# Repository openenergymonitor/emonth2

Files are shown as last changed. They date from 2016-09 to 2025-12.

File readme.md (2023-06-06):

# emonTH V2.0

**Low power wireless temperature and humidity node**

*V2.0 hardware revision adds support for SI7021 temperature and humidity. This sensor brings performance and power savings over the DHT22, see [sensor](sensor) folder of this repo for sensor evaluation and comparison.*

The emonTH V2 is an open-source, wireless, battery powered temperature and humidity monitoring node.

Data from the emonTH is transmitted via wireless RF (433MHz) to an emonPi / emonBase web-connected base-station for logging to Emoncms for data logging, processing and graphing.

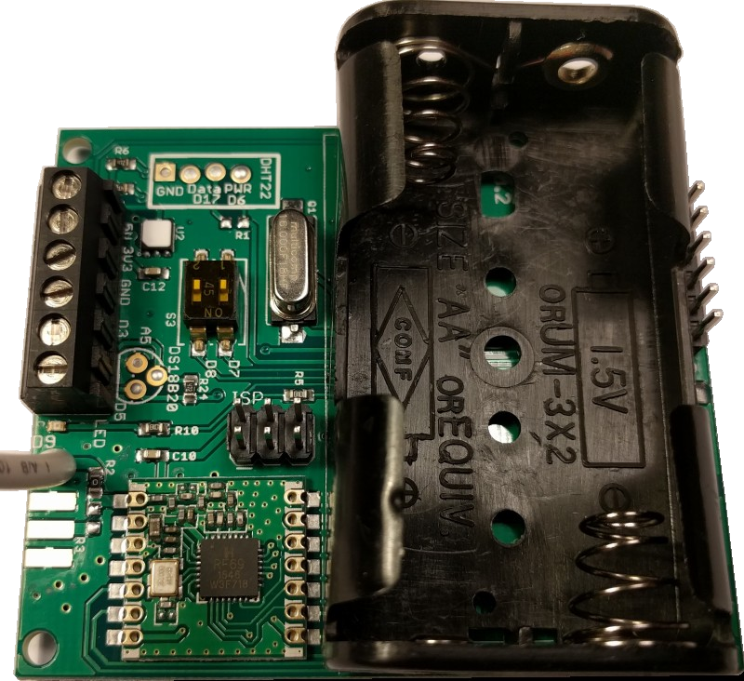
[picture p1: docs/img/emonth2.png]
emonTH V2


## Documentation

- [Overview](https://docs.openenergymonitor.org/emonth2/overview.html)
- [Installation](https://docs.openenergymonitor.org/emonth2/install.html)
- [Firmware](https://docs.openenergymonitor.org/emonth2/firmware.html)
- [Configuration](https://docs.openenergymonitor.org/emonth2/configuration.html)
- [Technical](https://docs.openenergymonitor.org/emonth2/technical.html)

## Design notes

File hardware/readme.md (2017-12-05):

# Board

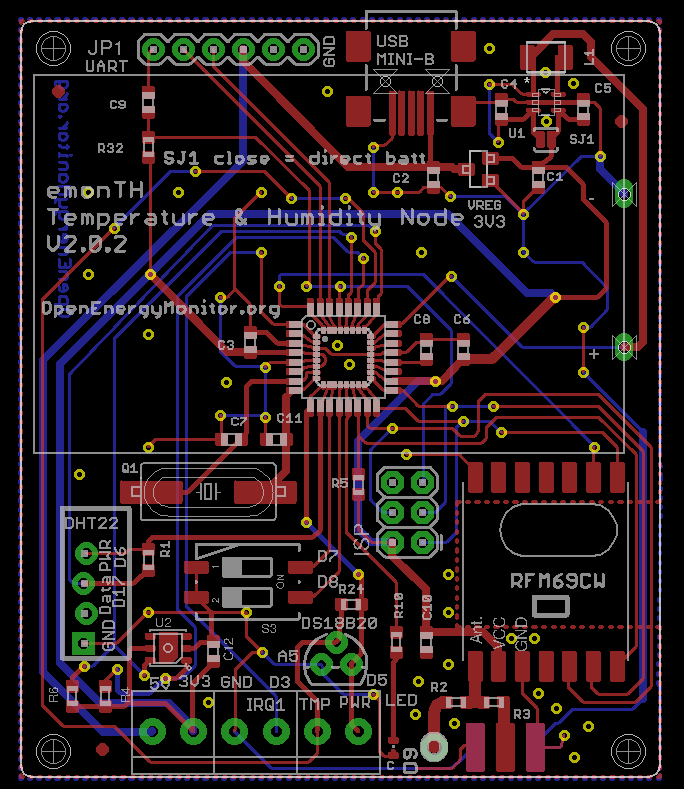
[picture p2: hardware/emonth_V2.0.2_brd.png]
board


# Schematic

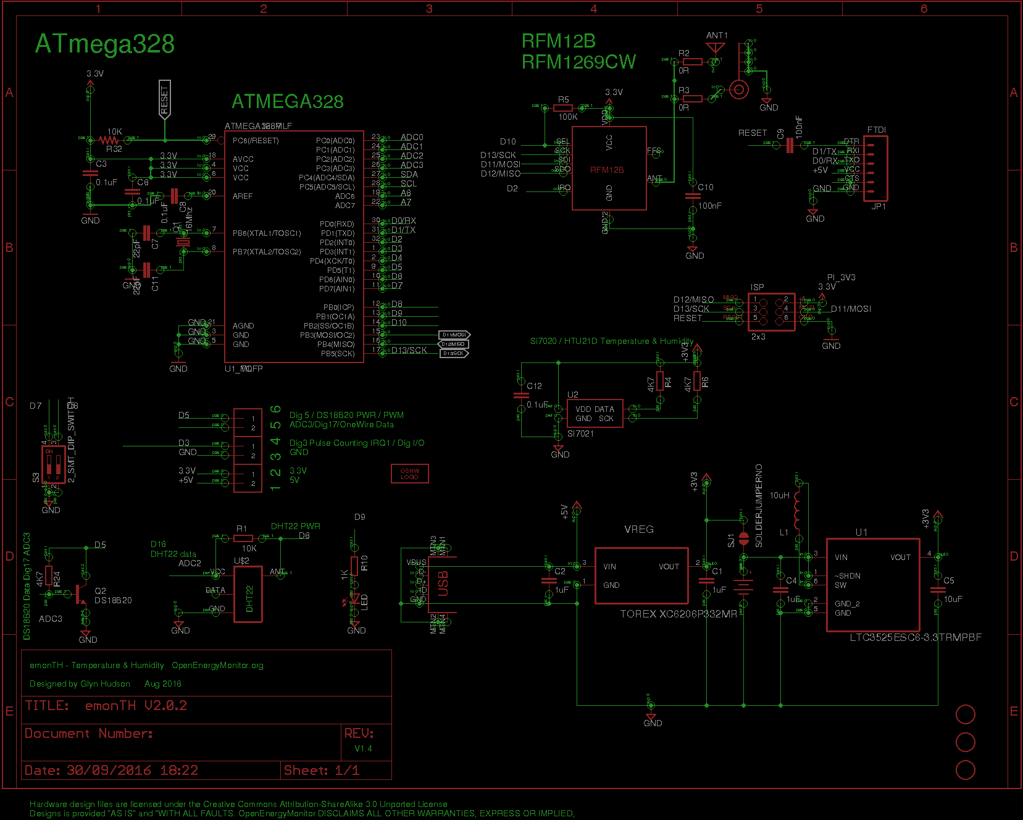
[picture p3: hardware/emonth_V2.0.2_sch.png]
emonTH V2 schematic


# Change log

## V2.0.2 (26th Sep 2016)

- Fix LED trace

## V2.0.1 (Aug 2016)

- Add SI7021 temperature & humidity sensor (see `si7021_eval` folder in emonth2 repo)
- Re-jig port map from emonTH V1.5 to make available I2C pins for SI7021

# Port Map

| | | | |
|---|---|---|---|
| Arduino | ATmega328 | Function | emonTH V2 |
| Analog 0 (D14) | PC0 | | |
| Analog 1 (D15) | PC1 | | 2x AA Battery Voltage |
| Analog 2 (D16) | PC2 | | DHT22 Data |
| Analog 3 (D17) | PC3 | | DS18B20 One-wire Data |
| Analog 4 (D18) | PC4 | (SDA) | SI7021 SDA (Data) |
| Analog 5 (D19) | PC5 | (SCL) | SI7021 SCL (SCK) |
| Analog 6 (D20) | | | |
| Analog 7 (D21) | | | |
| Digital 0 | PD0 | (RXD) | FTDI Tx |
| Digital 1 | PD1 | (TXD) | FTDI Rx |
| Digital 2 | PD2 | (int0) PWM | RFM69CW IRQ |
| Digital 3 | PD3 | (int1) PWM | Terminal block |
| Digital 4 | PD4 | | |
| Digital 5 | PD5 | PWM | DS18B20 PWR |
| Digital 6 | PD6 | PWM | DHT22 PWR |
| Digital 7 | PD7 | | DIP 1 |
| Digital 8 | PB0 | | DIP 2 |
| Digital 9 | PB1 | PWM | LED |
| Digital 10 | PB2 | (SS) PWM | RFM69CW SEL |
| Digital 11 | PB3 | (MOSI) PWM | RFM69CW SDI |
| Digital 12 | PB4 | (MISO) | RFM69CW SDO |
| Digital 13 | PB5 | (SCK) | RFM69CW SCK |

# BOM

|Qty |Value |Device |Package |Parts |Description |
|----|---|---|---|---|---|
|1 | |ANTENNA |PAD-01 |ANT1 |Antenna |
|1 | |LEDCHIPLED-0603-TTW  |CHIPLED-0603-TTW|LED |LED |
|4 |0.1uF |C-EUC0603 |C0603 |C3, C6, C8, C12|CAPACITOR, European symbol |
|2 |0R |R-EU_R0603 |R0603 |R2, R3 |RESISTOR, European symbol |
|1 |100K |R-EU_R0603 |R0603 |R5 |RESISTOR, European symbol |
|2 |100nF |C-EUC0603 |C0603 |C9, C10 |CAPACITOR, European symbol |
|1 |10K |R-EU_R0603 |R0603 |R1 |RESISTOR, European symbol |
|1 |10K |R-US_R0603 |R0603 |R32 |RESISTOR, American symbol |
|1 |10uF |C-EUC0603 |C0603 |C5 |CAPACITOR, European symbol |
|1 |10uH |INDUCTOR1210 |1210 |L1 |Inductors |
|1 |16Mhz |CRYSTALHC49UP |HC49UP |Q1 |CRYSTAL |
|1 |1K |R-EU_R0603 |R0603 |R10 |RESISTOR, European symbol |
|3 |1X2-3.5MM |1X2-3.5MM |1X2-3.5MM |J1, J2, J3 |3.5mm Terminal block |
|3 |1uF |C-EUC0603 |C0603 |C1, C2, C4 |CAPACITOR, European symbol |
|2 |22pF |C-EUC0603 |C0603 |C7, C11 |CAPACITOR, European symbol |
|1 |2_SMT_DIP_SWITCH |2_SMT_DIP_SWITCH |DIP_SWITCH_SMT  |S3 |Multicomp MCEMR-02-T |
|1 |2x3 |AVR_SPI_PRG_6PTH |2X3 |ISP |AVR ISP 6 Pin |
|1 |3V |3X_AAA_BATTERY_HOLDER|AAA_PCB_HOLDER  |U$3 |2x AA Battery Holder |
|3 |4K7 |R-EU_R0603 |R0603 |R4, R6, R24 |RESISTOR, European symbol |
|1 |ATMEGA168MLF |ATMEGA168MLF |MLF32 |U1_MLF |Atmel 32-pin 8-bit micro, 16k flash. |
|1 |ATMEGA328P |ATMEGA328_SMT |TQFP32-08 |U1_TQFP |32-Pin Atmega328 part |
|1 |DS18B20 |TRANSISTOR_NPNTO92 |TO-92 |Q2 |Transistor NPN |
|3 |FIDUCIAL |FIDUCIAL |FIDUCIAL_1MM |U$1, U$6, U$7  |For use by pick and place machines to calibrate the vision/machine, 1mm|
|1 |FTDI |FTDI_BASICPTH |FTDI_BASIC |JP1 |FTDI Basic: 3.3V and 5V |
|1 |LTC3525ESC6-3.3TRMPBF|LTC3525ESC6-3.3TRMPBF|SOT65P210X100-6N|U1 |Step-Up DC/DC Converter |
|1 |RF-LINK_TX |RF-LINK_TX |RF-LINK_TX |U$2 | |
|1 |RFM12B |RFM12B |RFM12B |RFM69CW | |
|1 |SI7021 |SI7021 |SI7021 |U2 |The Si7021 is an I2C Humidity and Temperature Sensor |
|1 |SMA_EDGE |SMA_EDGE |SMA-EDGE |J$1 |SMA Antenna Connector |
|1 |SOLDERJUMPERNO |SOLDERJUMPERNO |SJ_2S-NO |SJ1 |Solder Jumper |
|1 |TOREX XC6206P332MR |MCP1700T-3302E/TT |SOT95P237X112-3N|VREG |Low Quiescent Current LDO |
|1 |USB-MINIB-5PIN |USB-MINIB-5PIN |USB-MINIB-CISECO|U$5 |Mini-USB "B" connector with 5th pin broken out. |

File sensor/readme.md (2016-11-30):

# Temperature & Humidity Sensor Evaluation and Testing

| Metric | [HTU21D](https://octopart.com/htu21d-measurement+specialties-30374934) |[Si72021](https://octopart.com/si7021-a20-im-silicon+labs-52675246)| DHT22 | DHT22 vs HTU21D Difference| [BME280](https://octopart.com/bme280-bosch-52931981) |
| --- | ---|--- | --- | --- | --- |
| Cost in 1k off | £2.15|  £4.57 (July16) | 3.2 times cheaper (£3.15 less!) | £3.07 |
| Vcc |  1.9V - 3.6V | 3.3-6V | | 1.71 V - 3.6V |
| Humidity accuracy |  ±2% RH |  ±2%RH | n/a | ±3%RH |
| Humidity Range |  0-100% RH |  0-100% RH | n/a|  0-100% RH  |
| Temperature accuracy | ±0.4°C|  ±0.5°C | 40% more accurate | ±0.5 - ±1.0 |
| Temperature Range | -40°C +125°C  |  -40°C +80°C | 56% more accurate | -40°C +80°C  |
| Sleep Current | 0| 0.06uA |  15uA | 750 times less power | 0.1uA - 0.3uA |
| Measurement Current | 0. 0.09 mA |  0.5mA | 11 times less power | 0.714mA - 0.350mA |
| Measurement time | 0.01s | 0.01s - 0.0026s |  2s | 200 times faster | 0.013s |
| Energy consumed per sample| 2.97uJ |  3300uJ | 2000 times less power | |
| Time sampling per day* ||  2800s | | |
| Time sleeping per day* | |  83600s | | |
| Energy consumed per day*  ||  8700mJ [2] | 1115 times less energy per day!  | |

```
energy consumed (joule, J) = potential difference (volt, V) × charge (coulomb, C)
charge (coulomb, C) = current (ampere, A) × time (second, s)
energy consumed (joule, J)  = potential difference (volt, V) × current (ampere, A) × time (second, s)
```

## Energy consumed per day*

Energy consumed per day = energy consumed per sample + energy consumed while sleeping.

- **HTU21D:** (1400 * 0.0015mJ) + (3.3V * 0.00002mA * 86386 ) = 2.1mJ + 5.7mJ = 7.8mJ [1]
- **DHT22:**  (1400 * 3.3mJ) + (3.3V * 0.015mA * 83600) = 4.6mJ + 4.1J = 8.7J = 8700mJ   [2]

\*Assuming 1 sample per min and sleeping in between samples: 1400 samples per day

[Adafruit HTU21D Library](https://github.com/adafruit/Adafruit_HTU21DF_Library)

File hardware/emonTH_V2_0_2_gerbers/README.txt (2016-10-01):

# emonTx TH V2.0.2 - Sep 2016

- PCB to be 1.6mm thickness
- Solder Resist: Blue
- Finish: HASL

* No silkscreen should overlap pads
* Check Welsh Daragon logo on the rear is re-produced OK :-)

glyn.hudson@openenergymonitor.org
Tel: +441248672607
Mob: +447769871550

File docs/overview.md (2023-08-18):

<a class="btn" href="https://shop.openenergymonitor.com/emonth-temperature-humidity-node/">Buy in Shop</a>

# Overview

The emonTH V2 is an open-source, wireless, battery-powered temperature and humidity monitoring node.

Data from the emonTH is transmitted via wireless RF (433MHz) to an emonPi / emonBase web-connected base-station for logging to Emoncms for data logging, processing and graphing.

The emonTH V2 features a [Silicon Labs Si7021](https://www.silabs.com/Support%20Documents%2FTechnicalDocs%2FSi7021-A20.pdf) temperature and humidity sensor instead of the DHT22 sensor. The Si7021 is more accurate and significantly (2000 times!) lower power then the DHT22. This increases the emonTH battery life; from 10 months to several years. The Si7021 is also much smaller than the DHT22.

emonTH V2

The Si7021 sensor can be seen in the top right-hand corner of the PCB. The white film on top of the sensor is a dust film and should not be removed. The dust film is factory fitted and will protect the sensor from dust and air contaminants.

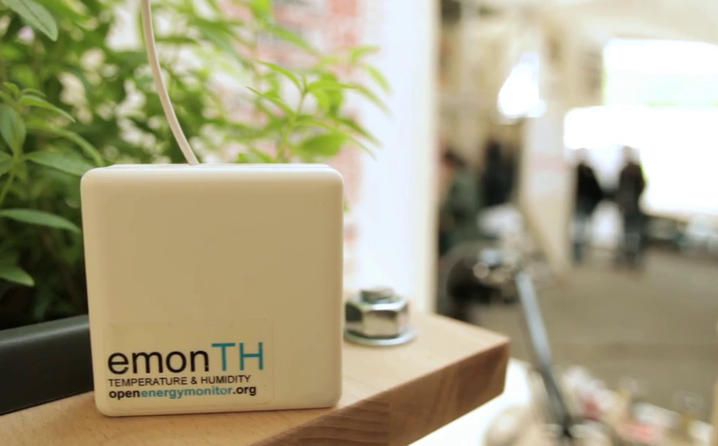
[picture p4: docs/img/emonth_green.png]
emonTH V2


As with all our hardware units the emonTH V2 is fully open-source and manufactured locally in North Wales, UK using non-conflict materials lead-free processes.

**emonTH V2 Features**

- Wireless temperature & humidity monitoring node
- Communicates with emonPi & emonBase via RF (433Mhz)
- 1yr+ battery life (2 x AA not included)
- Up to 4x emonTH can communicate to a single emonPi*
- Internal temperature & humidity + optional external probe
- Optional pulse sensor input

\* *More than 4x emonTH units can be connected to a single emonPi / emonBase with manual change of RF nodeID. This can be done via [serial node ID config](https://community.openenergymonitor.org/t/emontx-emonth-configure-rf-settings-via-serial-released-fw-v2-6-v3-2/2064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)*

- Microcontroller: Arduino compatible ATmega328p
- Internal Sensor: Si7021 (internal temperature & Humidity)
- External Sensor (OPTIONAL): DS18B20 external temperature sensor. See hardware wiki for connections
- Power: 2 x AA from onboard holder, LTC3525 3.3V DC-DC boost converter to extend battery life
- RF Radio: RFM69CW 433Mhz

**Si7021 Temperature & Humidity Sensor**

- Silicon Labs SI7021-A20-GM1R
- Power supply 1.9V - 3.6V
- Operating range humidity 0-80%RH; temperature -40~125 deg C
- Accuracy humidity +-3%RH
- Accuracy Temperature: +-0.4 degC
- Active current: 150uA
- Sleep current 0.06uA
- Measurement time: 2.6ms = 10ms

[See DHT22 VS Si7021 technical comparison table](https://github.com/openenergymonitor/emonth2/tree/master/sensor)

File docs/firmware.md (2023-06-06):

# Firmware

The emonTH2 firmware is based on Arduino.

## Available Firmware

### [emonTh2](https://github.com/openenergymonitor/emonth2/tree/master/firmware):

**New:** Support for three different radio formats is available: JeeLib Classic, JeeLib Native and **LowPowerLabs**.

## Updating firmware using an emonPi/emonBase

The easiest way of updating the emonTh2 firmware is to connect it to an emonPi or emonBase with a USB to UART cable and then use the firmware upload tool available at `Setup > Admin > Update > Firmware`.

The example images below show the earlier [Wicked Device / OpenEnergyMonitor Programmer](../electricity-monitoring/programmers/wicked-device.md). The programmer is the small board that plugs in to the emonTh2 on the 6-pin UART header. The [newer programmer](../electricity-monitoring/programmers/ftdi-programmer.md) currently available in the shop needs to be orientated the other way around. **Make sure that GND on the programmer matches up with GND on the emonTh2 board.**

Refresh the update page after connecting the USB cable. You should now see port ttyUSB0 appear in the ‘Select port` list.

*emonPi to emonTh2 programmer image*

Select port: `ttyUSB0`, Hardware: `emonTh2`, Radio format e.g: `RFM69 LowPowerLabs`:

*emonTh firmware upload image*

Click `Update Firmware` to upload the firmware.

## Upload using avrdude

Pre compiled firmware can be uploaded using a USB to UART programmer and avrdude: 

`avrdude -uV -c arduino -p ATMEGA328P -P /dev/ttyUSB0  -b 115200 -U flash:w:firmware.hex`

## How to compile and upload firmware

### PlatformIO Command Line

PlatformIO works great from the command line. See the excellent [PlatformIO Quick Start Guide](https://docs.platformio.org/en/latest/core/installation/index.html#super-quick-mac-linux) for installation instructions.

**Compile and upload emonTh2 firmware**

    git clone https://github.com/openenergymonitor/emonth2
    cd emonth2/firmware
    pio run -t upload

**View serial port with PlatformIO CLI**

    pio device monitor

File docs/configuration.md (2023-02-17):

# Configuration

- Battery operation is expected, although 5 V d.c. can be supplied via the FTDI connector or the screw terminal block if desired.
- Transmits readings from internal temperature and humidity sensor, also external DS18B20 temperature sensor can be connected if desired.
- Settings can be adjusted at power-up using the FTDI connector and a serial programmer.

## Setting up

Data is transmitted by radio approximately every 58 s, identified as Node 23. Changing the internal DIP switches before power-up can change this to Node 24, 25 or 26.

Adding an external temperature sensor before power-up will allow it to be recognised and the readings automatically included in the sent data.

## Additional set-up options

At power-up, if you have a serial monitor connected via the FTDI connector and set to 115200 baud with “both NL & CR” selected, you will see a “Welcome” message giving the software version number, the radio, pulse counter and temperature settings, and some more diagnostic messages. At the end is an invitation to enter the access code **+++**. You have a 5 s window to enter that (or you may ignore it, when after the delay, the emonTH will start up, you will see nothing more and you will not be able to change anything until you restart the sketch).

If you successfully enter the access code, you will see an advisory and a short menu:

Entering Settings mode...

Available commands:

- **l** list the settings
- **r** restore sketch defaults
- **s** save settings to EEPROM
- **v** show firmware version
- **x** exit, lock and continue
- **?** show this text again

- **w\<x\>** turn RFM Wireless data off: x = 0 or on: x = 1
- **b\<n\>** set r.f. band n = a single numeral: 4 = 433MHz, 8 = 868MHz, 9 = 915MHz (may require hardware change)
- **p\<nn\>** set the r.f. power. nn - an integer 0 - 31 representing -18 dBm to +13 dBm. Default: 25 (+7 dBm)
- **g\<nnn\>** set Network Group nnn - an integer (OEM default = 210)
- **n\<nn\>** set node ID n= an integer (standard node ids are 1..60)

- **m\<x\> \<yy\>** meter pulse counting:
  - x = 0 for OFF, x = 1 for ON, 
  - \<yy\> = an integer for the pulse minimum period in ms. (y is not needed, or ignored when x = 0)

- **t0 \<y\>** turn external temperature measurement on or off: y = 0 for OFF, y = 1 for ON

- **t\<x\> \<yy\> \<yy\> \<yy\> \<yy\> \<yy\> \<yy\> \<yy\> \<yy\>**
  - change an external temperature sensor's address or position:
  - x = a single numeral: the position of the sensor in the list (1-based)
  - yy = 8 hexadecimal bytes representing the sensor's address
  - e.g. 28 81 43 31 07 00 00 D
  - N.B. Sensors CANNOT be added.

Only the radio, pulse and temperature sensor settings can be changed, the temperature and humidity sensors cannot be calibrated. Normally, you should save ‘ **s’** the settings before you exit ‘ **x’** , so that they will be retained and used forever (until changed again).

If you turn the radio off and serial data on ( **w2** ), only the serial data in a format compatible with the emonHub Serial Interfacer will be sent to the FTDI port. ( **w3** ) will send data both by radio and the serial port, the default is radio only ( **w1** ).

If you turn the radio power up above the default value of 25, ensure you select the frequency band that matches the radio module fitted, else the radio module itself could be destroyed. Turning the power up will significantly reduce the battery life, conversely turning the power down will increase the battery life.

If you change the NodeID, then the internal DIP switches add 0, 1, 2 or 3 to the new NodeID.

The meter pulse minimum period inhibits the effect of ‘contact bounce’ if the pulses come from a mechanical switch. The period can be lengthened if necessary, or shortened to zero if the pulses come from an electronic switch.

The external temperature sensor is only turned on if one is detected at the start. A connected sensor can be turned off to save power without needing to disconnect it.

If you need two or more sensors, then although the sketch supports up to four, it will be necessary to edit and recompile the sketch to include the additional readings in the sent data. The ability to manually edit the sensor addresses will allow the order of the sensors to be preserved in the event that one has been replaced. If a replacement sensor is not recognised, make a note of the addresses of all, set the address of the first to “00 00 00 00 00 00 00 00” and restart the sketch. You can then manually re-enter the addresses in the order you require and save the settings.

## Data Output

The output by radio is, in order:

1. Internal temperature
2. External temperature
3. Humidity
4. Battery voltage
5. Pulse Count.

The “key:value” pairs serial output for the EmonESP & EmonHubOEMInterfacer sends the following

1. Internal temperature temp
2. External temperature tempex
3. Humidity humidity
4. Battery voltage batt
5. Pulse Count pulse

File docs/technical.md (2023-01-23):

# Power Consumption

The motivation behind replacing the DHT22 Temperature & Humidity sensor used on the emonTH V1 with the Si7021 Temperature & Humidity sensor on the emonTH V2 was the power saving benefits.

See the sensor folder in the emonTH2 repo for a power consumption comparision between the DHT22 and Si7021.

This document contains real-world emonTH2 power consumption as measured using a multi-meter & scope resistor voltage drop method [explained in previous blog post](http://blog.openenergymonitor.org/2013/07/new-oscilloscope/).

Here is a scope trace illustrating the emonTH power consumption during a sensor sample:

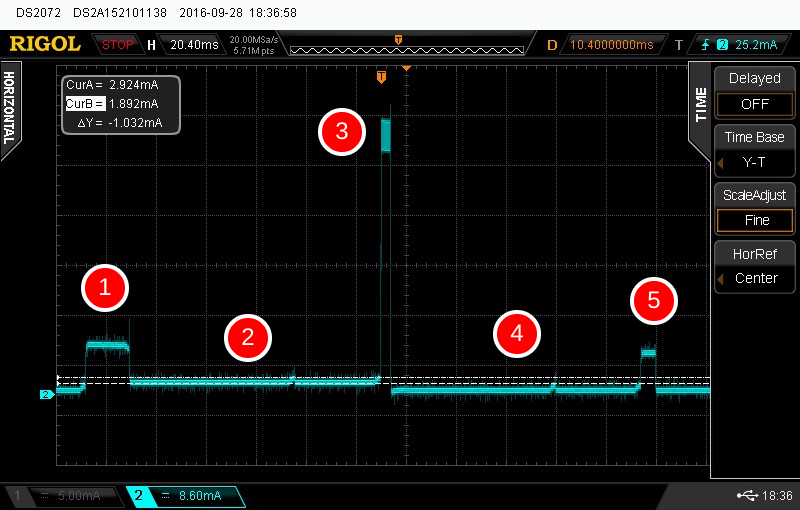
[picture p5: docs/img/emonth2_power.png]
emonth2 power consumption


1. Atmega328 wakes up, starts sensors and takes readings: 17.5ms @ 8.4mA

2. Atmega328 goes back to watchdog sleep but leaves SPI initialised waiting for wait for RFM to initialise: 100ms @ 2mA - \*now reduced ([see code](https://github.com/openenergymonitor/emonth2/blob/master/firmware/src/src.ino#L331))

3. RFM69CW transmission: 4ms @ 44mA

4. Wait for RF transmission to finish: 100ms @ 0.06mA

5. ATmega328 wakes up to Print data to serial UART: 5ms @ 7.2mA

Time taken for sample = 17.5 + 100 + 4 + 100 + 5 = **226.5ms**

Average current per sample = (17.5*8.4) + (100*2) + (4*44) + (100*0.06) + (5*7.2) / 225.5 =  565 / 225.5 = 2.5mA

After sensor sample is complete the ATmega328 goes back to full watchdog sleep for consuming 0.06mA. This base quiescent consumption includes the quiescent power consumption of the LTC3525 DC-DC converter. See original emonTH hardware blog post for [emonTH DC-DC converter design](https://blog.openenergymonitor.org/2013/10/emonth-update-hardware/).

Assuming one reading per min (current default) the emonTH is off (sleeping for): number of ms in one min - on time = 60000ms - 225.5ms = 59774.5

***

To summarise:

- On current  = 2.5mA (average)
- On time     = 226ms
- Off current = 0.06mA
- Off time    = 59774.5 ms

[Oregon Embedded online battery life calculator tool](http://oregonembedded.com/batterycalc.htm) can now be used to calculate battery live. Assuming using 2 x AA alkaline batteries @ 2700 mAhr each = 5400\*

\* *The 2 x AA batteries are connected in series but since uses emonTH uses a DC-DC converter capacity is effectivly 2xAA capacity (mius losses), [see forum post](https://community.openenergymonitor.org/t/emonth-v2/1696/18?u=glyn.hudson)*

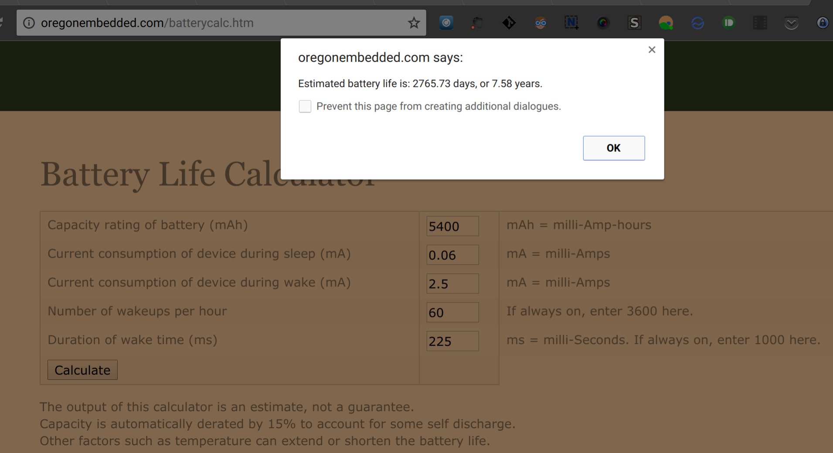
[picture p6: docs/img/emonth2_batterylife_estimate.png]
emonth V2 estimated battery life


Given the measured power consumption the emonTh2 is estimated to have a battery life of 7.6 years!

Plugging in the [power consumption figures from the emonTh V1](http://blog.openenergymonitor.org/2013/10/emonth-update-software-power/) (with DHT22) into the calculator a 1.4 year battery life is estimated.

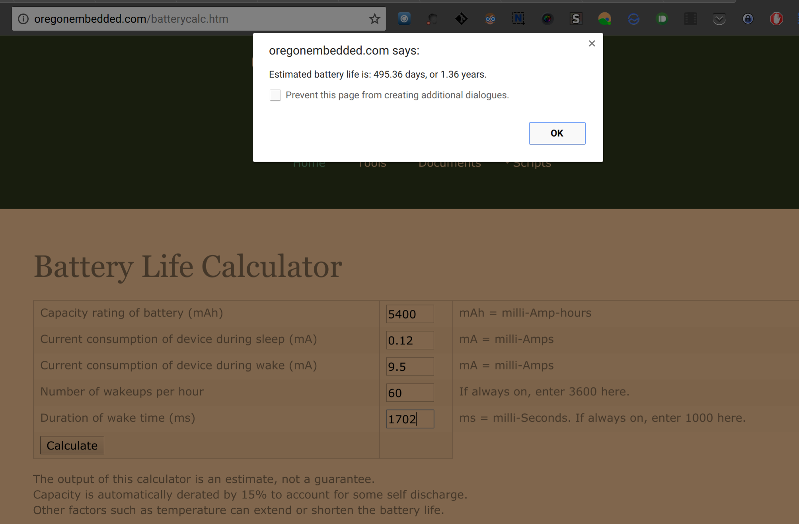
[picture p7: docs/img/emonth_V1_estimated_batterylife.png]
emonth V1 estimated battery life


From [real world testing](http://blog.openenergymonitor.org/2015/02/real-world-emonth-battery-life) is been established that the emonTh V1 actually achieves a 8 month battery life. This is 57% less than the estimated figure.

Assuming the battery life calculator is overestimating by the same amount for the emonTH V2 we can **expect a real world battery life of just over 5 years**, which is not too bad :-p

I have setup a battery life test with the emonTh V2 with Si7021 sensor, I will report back in a couple of years :-)

***

See [forum topic discussion](https://community.openenergymonitor.org/t/emonth-v2/1696/18)

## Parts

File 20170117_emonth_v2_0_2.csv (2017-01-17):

Qty | Line Item | Manufacturer | MPN | Octopart URL | Schematic Reference | Internal Part Number | Description | Total Qty (@ Batch Size: 1000) | SKU | SKU | SKU | Packaging | Packaging | Packaging | Unit Price (@ Batch Size: 1000) | Unit Price (@ Batch Size: 1000) | Unit Price (@ Batch Size: 1000) | In Stock | In Stock | In Stock | MOQ | MOQ | MOQ | URL | URL | URL | Distributor [Custom] | SKU [Custom] | Packaging [Custom] | Unit Price (@ Batch Size: 1000) [Custom] | Line Total [Custom] | Batch Total [Custom] | In Stock [Custom] | MOQ [Custom] | URL [Custom] | Notes
 |  |  |  |  |  |  |  |  | Digi-Key | Mouser | Newark | Digi-Key | Mouser | Newark | Digi-Key | Mouser | Newark | Digi-Key | Mouser | Newark | Digi-Key | Mouser | Newark | Digi-Key | Mouser | Newark
6 | CC0603KRX7R9BB104 | Yageo | CC0603KRX7R9BB104 | https://octopart.com/cc0603krx7r9bb104-yageo-42244635 | C3, C6, C8, C9, C10, C12 |  | 100nF | 6000 | 311-1344-2-ND | CC0603KRX7R9BB104 |  | Tape & Reel |  |  | 0.0044291786 | 0.00575218 |  | 4064000 | 39775 |  | 4000 |  |  | https://octopart.com/click/track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 | https://octopart.com/click/track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 |  | SOS electronic | K0603 0,1UF X7R 50V 10% REEL |  | 0.0017550221903285194 | 0.010530133141971116 | 10.530133141971117 | 115000 | 4000 | https://octopart.com/click/track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
3 | CC0603KRX7R8BB105 | Yageo | CC0603KRX7R8BB105 | https://octopart.com/cc0603krx7r8bb105-yageo-24490981 | C1, C2, C4 |  | 1uF | 3000 | 311-1802-1-ND | CC0603KRX7R8BB105 | 76T5629 | Cut Tape |  | Tape & Reel | 0.013147840000000001 | 0.0123261 |  | 83636 | 19816 | 0 | 1 |  | 4000 | https://octopart.com/click/track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 | https://octopart.com/click/track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 | https://octopart.com/click/track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 | Arrow | CC0603KRX7R8BB105**MULT1 | Cut Tape | 0.010353924 | 0.031061772 | 31.061772000000005 | 3000 | 1 | https://octopart.com/click/track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
2 | CC0603KRX7R9BB223 | Yageo | CC0603KRX7R9BB223 | https://octopart.com/cc0603krx7r9bb223-yageo-41224721 | C7, C11 |  | 22pF | 2000 | 311-1370-1-ND | CC0603KRX7R9BB223 |  | Cut Tape |  |  | 0.0101567064 | 0.00986088 |  | 56263 | 16151 |  | 1 |  |  | https://octopart.com/click/track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 | https://octopart.com/click/track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 |  | TME | CC0603KRX7R9223 |  | 0.0016434800000000001 | 0.0032869600000000002 | 3.28696 | 111700 | 100 | https://octopart.com/click/track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
1 | CRCW0603100KFKEA | Vishay | CRCW0603100KFKEA | https://octopart.com/crcw0603100kfkea-vishay-39670900 | R5 |  | 100K | 1000 | 541-100KHCT-ND | CRCW0603100KFKEA |  | Cut Tape |  |  | 0.0045524396 | 0.01479132 |  | 645059 | 535385 |  | 1 |  |  | https://octopart.com/click/track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 | https://octopart.com/click/track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 |  | Arrow | CRCW0603100KFKEA**MULT1 | Cut Tape | 0.001479132 | 0.001479132 | 1.479132 | 3124 | 1 | https://octopart.com/click/track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
1 | CRCW060310K0FKEA | Vishay | CRCW060310K0FKEA | https://octopart.com/crcw060310k0fkea-vishay-55388213 | R32 |  | 10K | 1000 | 541-10.0KHCT-ND | CRCW060310K0FKEA |  | Cut Tape |  |  | 0.0045524396 | 0.01479132 |  | 5208626 | 1173527 |  | 1 |  |  | https://octopart.com/click/track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 | https://octopart.com/click/track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 |  | Arrow | CRCW060310K0FKEA**MULT1 | Cut Tape | 0.001479132 | 0.001479132 | 1.479132 | 2679 | 1 | https://octopart.com/click/track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
1 | CC0603MRX5R5BB106 | Yageo | CC0603MRX5R5BB106 | https://octopart.com/cc0603mrx5r5bb106-yageo-42335507 | C5 |  | 10uF | 1000 | 311-1448-1-ND | CC0603MRX5R5BB106 | 59M4957 | Cut Tape |  | Cut Tape | 0.0346116888 | 0.03451308 | 0.020543500000000003 | 262529 | 18089 | 0 | 1 |  | 10 | https://octopart.com/click/track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 | https://octopart.com/click/track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 | https://octopart.com/click/track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 | Chip One Stop Japan | C1S900100757762 | Cut Tape | 0.010541528338872194 | 0.010541528338872194 | 10.541528338872194 | 1350 | 50 | https://octopart.com/click/track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
1 | CRCW06031K00FKEA | Vishay | CRCW06031K00FKEA | https://octopart.com/crcw06031k00fkea-vishay-55433929 | R10 |  | 1K | 1000 | 541-1.00KHCT-ND | CRCW06031K00FKEA |  | Cut Tape |  |  | 0.0045524396 | 0.01479132 |  | 1116949 | 610945 |  | 1 |  |  | https://octopart.com/click/track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 | https://octopart.com/click/track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 |  | Arrow | CRCW06031K00FKEA**MULT1 | Cut Tape | 0.001479132 | 0.001479132 | 1.479132 | 20369 | 1 | https://octopart.com/click/track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
3 | CRCW06034K70FKEA | Vishay | CRCW06034K70FKEA | https://octopart.com/crcw06034k70fkea-vishay-39455708 | R4, R6, R24 |  | 4K7 | 3000 | 541-4.70KHCT-ND | CRCW06034K70FKEA |  | Cut Tape |  |  | 0.0045524396 | 0.01479132 |  | 359295 | 414514 |  | 1 |  |  | https://octopart.com/click/track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 | https://octopart.com/click/track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 |  | Chip One Stop Global | C1S803603318716 |  | 0.0036568198306570444 | 0.010970459491971132 | 10.970459491971134 | 16234 | 200 | https://octopart.com/click/track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
1 | LQH32CN100K33L | Murata | LQH32CN100K33L | https://octopart.com/lqh32cn100k33l-murata-5372096 | L1 |  | 10uH | 1000 | 490-6614-1-ND | LQH32CN100K33L | 38K3981 | Cut Tape |  | Cut Tape | 0.1220941292 | 0.09532184 | 0.1479132 | 24037 | 11386 | 1882 | 1 |  | 1 | https://octopart.com/click/track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 | https://octopart.com/click/track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 | https://octopart.com/click/track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 | Component Sense | LQH32CN100K33L |  | 0.041087000000000005 | 0.041087000000000005 | 41.087 | 2601 | 1 | https://octopart.com/click/track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
1 | ATMEGA328(P)-AU | Atmel | ATMEGA328P-AU | https://octopart.com/atmega328p-au-atmel-42498373 | U1_TQFP |  | ATMEGA328P | 1000 | ATMEGA328P-AU-ND | ATMEGA328P-AU | 68T2935 | Tray |  |  | 1.50131898 | 1.3147840000000002 | 1.4873494 | 5508 | 5933 | 492 | 1 |  | 1 | https://octopart.com/click/track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 | https://octopart.com/click/track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 | https://octopart.com/click/track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 | microchipDIRECT | ATMEGA328P-AU | Tray | 1.2654796000000001 | 1.2654796000000001 | 1265.4796000000001 | 0 | 250 | https://octopart.com/click/track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
1 | MCRSD16000F183000RR | Multicomp | MCRSD16000F183000RR | https://octopart.com/mcrsd16000f183000rr-multicomp-10528717 | Q1 |  | CRYSTAL, 16MHZ, 18PF, HC49-US, SMD | 1000
1 | XC6206P332MR | Torex | XC6206P332MR | https://octopart.com/xc6206p332mr-torex-5365305 | VREG |  | TOREX XC6206P332MR | 1000 |  |  |  |  |  |  |  |  |  |  |  |  |  |  |  |  |  |  | Quest | XC6206P332MR |  | 0.21365240000000002 | 0.21365240000000002 | 213.65240000000003 | 2405 |  | https://octopart.com/click/track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
1 | LTC3525ESC6-3.3#TRMPBFTR-ND | Linear Technology | LTC3525ESC6-3.3#TRMPBF | https://octopart.com/ltc3525esc6-3.3%23trmpbf-linear+technology-442497 | U1 |  | DC DC CONV, 400MA, 3.3V, SC70-6 | 1000 | LTC3525ESC6-3.3#TRMPBFTR-ND |  |  | Tape & Reel |  |  | 1.7421052348 |  |  | 2000 |  |  | 500 |  |  | https://octopart.com/click/track?country=ES&ak=68b25f31&sig=05e6c1c&sid=459&ppid=442497&vpid=1094416&ct=offers |  |  | Chip One Stop Japan | C1S424500302103 | Cut Tape | 1.7375346710278998 | 1.7375346710278998 | 1737.5346710278998 | 369 | 1 | https://octopart.com/click/track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
1 | SI7021-A20-GM1R | Silicon Labs | SI7021-A20-GM1R | https://octopart.com/si7021-a20-gm1r-silicon+labs-52675244 | U2 |  | Temperature & Humidity Sensor: tape and reel with protective coating -40 to +85C | 1000 | SI7021-A20-GM1R-ND | SI7021-A20-GM1R |  | Tube |  |  |  | 2.6049158 |  | 0 | 4802 |  | 2500 |  |  | https://octopart.com/click/track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 | https://octopart.com/click/track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 |  | Mouser | SI7021-A20-GM1R |  | 2.6049158 | 2.6049158 | 2604.9158 | 4802 |  | https://octopart.com/click/track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
1 | 692-0975 | Lite-On | LTST-C190GKT | https://octopart.com/ltst-c190gkt-lite-on-549821 | LED |  | Green LED 1.85V 60mcd | 1000 | 160-1183-1-ND | LTST-C190GKT |  | Cut Tape |  |  | 0.039936564 | 0.04273048 |  | 685663 | 116608 |  | 1 |  |  | https://octopart.com/click/track?country=ES&ak=68b25f31&sig=0316225&sid=459&ppid=549821&vpid=1103326&ct=offers | https://octopart.com/click/track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 |  | Digi-Key | 160-1183-1-ND | Cut Tape | 0.039936564 | 0.039936564 | 39.936564000000004 | 685663 | 1 | https://octopart.com/click/track?country=ES&ak=68b25f31&sig=0316225&sid=459&ppid=549821&vpid=1103326&ct=offers
1 | MCEMR-02-T | Multicomp | MCEMR-02-T | https://octopart.com/mcemr-02-t-multicomp-7505473 | S3 |  | SWITCH, 2 WAY, SPST, FLUSH | 1000 |  |  |  |  |  |  |  |  |  |  |  |  |  |  |  |  |  |  | element14 APAC | 1524005 |  | 0.5229696803112315 | 0.5229696803112315 | 522.9696803112315 | 17900 | 1 | https://octopart.com/click/track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
1 | BH-321-1P |  |  |  | U$3 | Rapid: 18-2965 | TruPower BH-321-1P 2 X AA PCB Battery Holder | 1000 |  |  |  |  |  |  |  |  |  |  |  |  |  |  |  |  |  |  | Rapid | 18-2965 |  | 0.162 | 0.162 | 162
1 | CTB3051/6BK | Boss Enclosures | CTB3051/6BK | https://octopart.com/ctb3051%2F6bk-boss+enclosures-71239123 | Terminal Block J1 - J3 | Rapid: 21-4709 | TERMINAL BLOCK 3.5MM PITCH 6 WAY | 1000
1 | M20-9980346 | Harwin | M20-9980346 | https://octopart.com/m20-9980346-harwin-5436545 | ISP |  | PIN HEADER STRAIGHT 6 WAY DIL 2.54MM (2X3) | 1000 | 952-2121-ND | M20-9980346 |  | Bulk |  |  | 0.090227052 | 0.0903914 |  | 39317 | 7135 |  | 1 |  |  | https://octopart.com/click/track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 | https://octopart.com/click/track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 |  | Digi-Key | 952-2121-ND | Bulk | 0.090227052 | 0.090227052 | 90.227052 | 39317 | 1 | https://octopart.com/click/track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
1 | M20-9990646 | Harwin | M20-9990646 | https://octopart.com/m20-9990646-harwin-5444450 | JP1 |  | PIN HEADER STRIGHT 6 PIN – FTDI (1X6) | 1000 | 952-2270-ND | M20-9990646 |  | Bulk |  |  | 0.090227052 | 0.0903914 |  | 16526 | 19484 |  | 1 |  |  | https://octopart.com/click/track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 | https://octopart.com/click/track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 |  | Digi-Key | 952-2270-ND | Bulk | 0.090227052 | 0.090227052 | 90.227052 | 16526 | 1 | https://octopart.com/click/track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
1 | PP000723 | Pro-Power | PP000723 | https://octopart.com/pp000723-pro-power-55834557 | ANT1 |  | 100m Whip Antenna 22AWG, WHITE - 165mm 433Mhz | 1000
1 | CRCW06030000Z0EB | Vishay | CRCW06030000Z0EB | https://octopart.com/crcw06030000z0eb-vishay-42505985 | R2 |  | Zero Ohm Jumper | 1000 | 541-2968-1-ND | CRCW06030000Z0EB |  | Cut Tape |  |  | 0.0033526992000000003 | 0.0065739200000000005 |  | 14104 | 83496 |  | 1 |  |  | https://octopart.com/click/track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 | https://octopart.com/click/track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 |  | Chip One Stop Global | C1S803601536044 |  | 0.0016212143583231031 | 0.0016212143583231031 | 1.6212143583231031 | 9690 | 200 | https://octopart.com/click/track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

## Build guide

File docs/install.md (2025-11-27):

<a class="btn" href="https://shop.openenergymonitor.com/emonth-temperature-humidity-node/">Buy in Shop</a>

# EmonTH v2 Install

Data from the emonTH is transmitted via wireless RF (433MHz) to an emonPi / emonBase web-connected base-station for logging to Emoncms for data logging, processing and graphing.

With the 2x AA batteries installed and the emonTH powered up. **The emonTH is designed to appear automatically in the emoncms input list on the emonPi/base**. For systems with only one emonTH no further hardware setup is required.

If more than one emonTH is to be used with the same base-station, each emonTH will need a different RF node ID.

emonTH V2

## Standard setup

### 1. Power Up

- Power emonTH from 2 x AA batteries
- Alternatively 5V DC can be wired into terminal block if required

### 2. Indicator LED

- Illuminates solid (dimly) for a few seconds at first power up
- LED should then extinguish to indicate successful sensor detection
- Flashing LED indicates sensor detection failure
- To preserve battery LED does NOT flash regularly during operation

### 3. Emoncms Setup

  - RF transmission from the emonTH will be picked up automatically and data will appear in local Emoncms Inputs page.
  - If [Remote logging](../emoncms/intro-remote.md) has been setup, data will also be posted to Emoncms.org.
  - See guide [Log Locally](../emoncms/intro-rpi.md) for an overview of logging inputs to feeds. For EmonTH inputs select a feed interval 60s or greater:
  
```{note}
Important: the emonTH reports data at a 60s interval, it's important to log the data to emoncms with a 60s inerval as shown below.
```

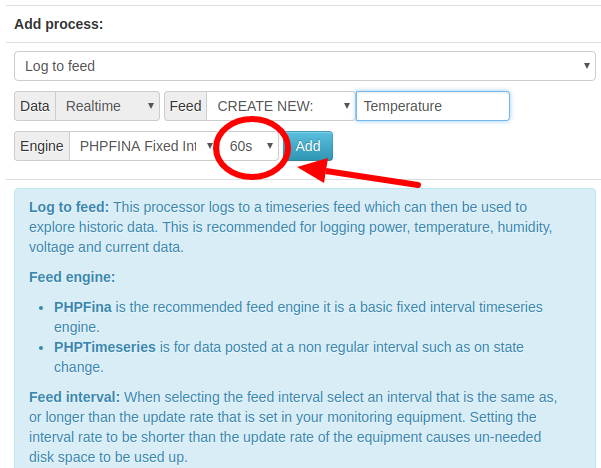
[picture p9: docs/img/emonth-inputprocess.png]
emonth input process


```{note}
If using more than 4x emonTH units (with custom RF node ID or modified firmware) [emonhub.conf node decoders will need to be setup](https://github.com/openenergymonitor/emonhub/blob/emon-pi/configuration.md).
```

---

## Changing the emonTH node ID

**DIP Switch Config**<br>
The on-board DIP switch can be used to select up to four node IDs:

| DIP 1 | DIP 2 | RF node ID V1.x firmware | RF node ID V2.x firmware |
|---|---|---|---|
| OFF | OFF | 19 (default) | 23 (default) |
| ON | OFF | 20 | 24 |
| OFF | ON | 21 | 25 |
| ON | ON | 22 | 26 |

**Serial Config**<br>
The emonTH node ID can also be changed using a USB to UART cable and the Arduino IDE.

## Add: External temperature sensor/s

The standard emonTH2 firmware supports connecting one external DS18B20 temperature sensor. 

- Black: GND
- Red: Power (digital I/O 5 is used as the power pin to enable sensor power-down between readings to save power)
- White: ADC5 (Dig 18) one-wire bus 

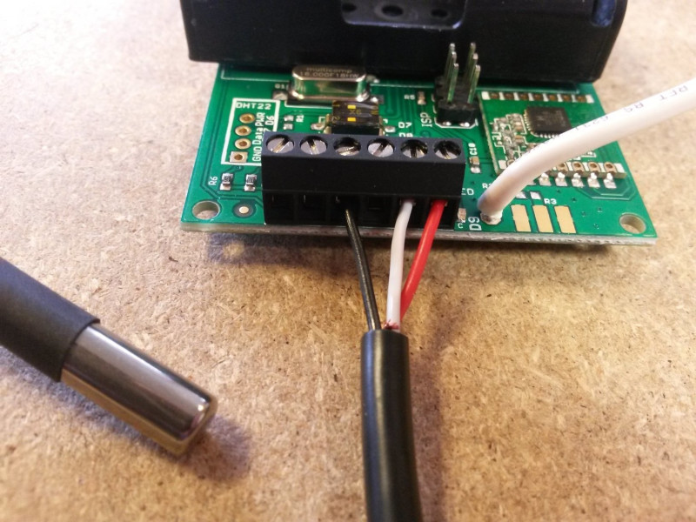
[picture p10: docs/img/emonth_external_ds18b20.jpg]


### Multiple temperature sensors

The master branch supports multiple external DS18B20 sensors. It is configured to only read and publish the output of the first sensor by default.

In order to add more sensors, you need to do four separate things.

1. Connect the additional sensors on the terminals
2. Modify the source files
   1. Check out the repository and open `emonth2.ino`. 
   2. Then Increase the value of `EXTERNAL_TEMP_SENSORS` to match the number of connected sensors here [https://github.com/openenergymonitor/emonth2/blob/master/firmware/emonth2.ino#L134]
   3. Upload the firmware with `pio run -t upload`
3. Update the sensor configuration in EMonHub to match your number of external sensors. For example, for two external sensors change it like this, by adding an additional external temperature under `names`, `datacodes` and `scales`:
```
    [[25]]
        nodename = emonth2_25
        [[[rx]]]
            names = temperature, external temperature 1, external temperature 2, humidity, battery, pulsecount
            datacodes = h, h, h, h, h, L
            scales = 0.1, 0.1, 0.1, 0.1, 0.1, 1.0
            units = C, C, %, V, p
```
4. You may need to change the setting for enabling/disabling the external probes on the serial console by hitting `+++` and `enter` after a reset and entering `t0 1` after the prompt

## Add: External optical pulse sensor

The EmonTH has a digital input (with interrupt) that can be used for pulse counting. This can be used for wired pulse counting or with the Optical LED pulse sensor.

To use the Optical LED Pulse sensor the easiest way is to remove the RJ45 connector and then strip back the black sheathing to reveal the red (3.3V power), black (GND) and blue (pulse) wires.

Connect the red wire to the 3.3V terminal, the black wire to the GND terminal and the blue wire to the terminal labelled D3 (top) or IRQ1/D3 Pulse Counting (bottom of the board).

- Red: 3.3V
- Black: GND
- Blue: IRQ1/D3

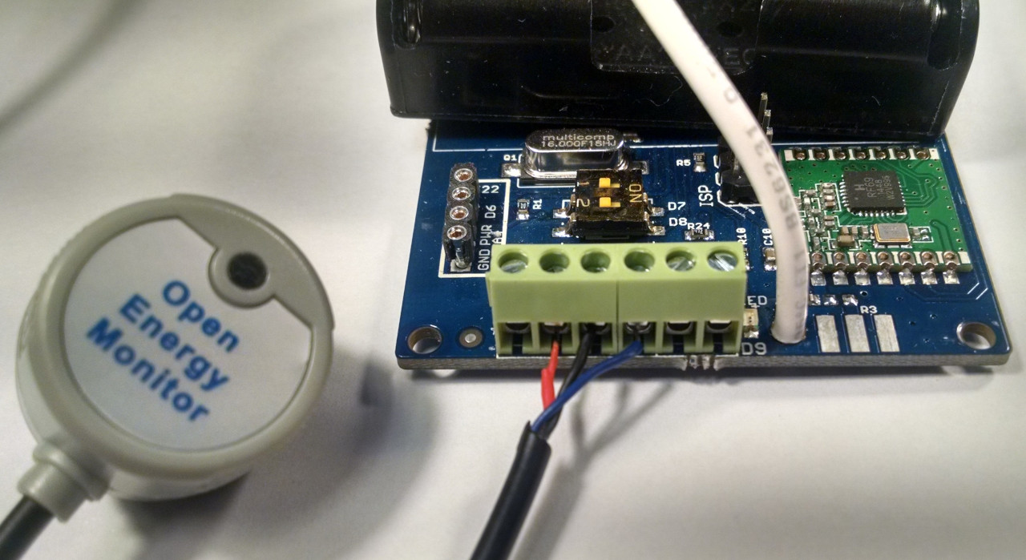
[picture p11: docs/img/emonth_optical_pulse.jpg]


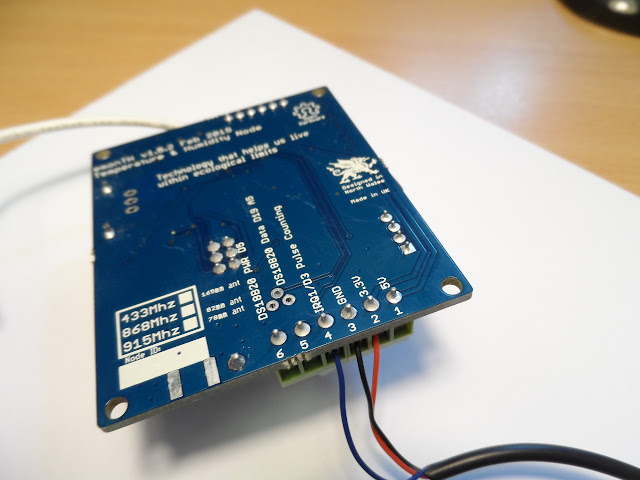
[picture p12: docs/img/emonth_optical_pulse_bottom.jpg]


**Input pull-up**<br>
There is an input pull-up inside the pulse (IRQ) input that is enabled in the standard sketch. Therefore, you can connect a volt-free contact or an SO output between screw terminal 4 (IRQ input, SO+) and screw terminal 3 (GND, SO-) without the need for an additional resistor. If you must connect your contacts between VCC (screw terminal 2) and screw terminal 4, then you must add a pull-down resistor of resistance low enough to overcome the internal pull-up resistor, or you can use a higher-value resistor and modify the sketch to disable the internal pull-up.

If you are using a reed switch, you may find that you get more than one count per pulse. Adding a 0.1 µF capacitor across the reed switch has been shown to eliminate this problem. 

**Emoncms input processing**<br>
To record the total accumulated pulse count in emoncms use the wh_accumulator input process which detects resets continuing the total pulse count accumulation from the last value before the reset.

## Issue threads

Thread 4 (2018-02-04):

Initial values always Zero

pb66, 2018-02-04:
Upon (re)inserting batteries the first payload is always all zeros (except pulse count which is always 1).

I haven't looked into this thoroughly yet, just making a note here at this stage for future investigation.

Either the settle time to the first packet needs extending, the first payload needs to be discarded or the order of events changed so only a properly populated payload is sent.

A zero temperature reading is often a valid temperature reading so a 0°C value should never be sent unless it is a true reading, this is why we moved to out of range 300°C error codes.

Plus there should never be an instance where 0v battery voltage is recorded, if the battery voltage was truly 0v, how was the data sent?

glynhudson, 2018-02-15:
Agree it will be best if this did not happen. A warm up. Should be defined to allow the unit
 settle before posting it's first values. I wonder if you're picking up the rf factory test packets

jonathandreyer, 2020-03-29:
Hi everyone, I have been using an emonth2 with emoncms from several years.
If you are interested, I can try to fix this bug. However, I don't know your RF factory test packets. Is it necessary to send zero value or we can send (as a test) real value?

SlyRemarks, 2021-10-05:
Fixed in latest release, V3.2.6. Factory test now uses network group 1.

Closed 2021-10-05.

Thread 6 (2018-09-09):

Adjusting sensitivity of optical sensor

danbates2, 2018-09-09:
Based on my observations and testing done by @kempson
https://community.openenergymonitor.org/t/adjusting-sensitivity-of-optical-pulse-sensor/8399/21

Rather than use the internal pull-up of the atmega, it's probably better to have an external pull-down and 0.1uF capacitor-to-gnd on the interrupt/signal line of the optical sensor. This would help decrease the sensitivity of the sensor and avoid light leakage issues. Also, the cap will help with noisy environments, as it did for my "connecting to RPi project".

Finding an good enough and balanced (reducing sensitivity vs maintaining strong output) pull-down value hasn't been done rigorously yet, when I get another sensor I'll do some checking, I've used a 50k pull-down and that worked fine on the RPi project.

glynhudson, 2018-09-18:
>Rather than use the internal pull-up of the atmega, it's probably better to have an external pull-down and 0.1uF capacitor-to-gnd on the interrupt/signal line of the optical sensor. This would help decrease the sensitivity of the sensor and avoid light leakage issues. Also, the cap will help with noisy environments, as it did for my "connecting to RPi project".

Yes, I did test using an external pull-up when in the design phase for the emonTH. However, I found that using the internal pull up provided adequate performance when using our standard optical pulse counting sensor without requiring additional components. Possible if using other sensors or direct pulse counting external components would be desirable.

Thanks for sharing the results of your testing, it it's proven that an external pull-down will significantly improve performance I would happily consider adding it on a future version of emonTH.

danbates2, 2018-09-19:
I'm using a 45k pull-down on my RPi setup, I'll be able to report on it's accuracy against the meter in about 2 weeks.
Further thoughts below, feel free to read, or wait for my result.

- - -

@Kempson's test result when the sensor is in darkness **is** the proof that a pull-down is better.

> Using a milliameter connected from IRQ to ground, with the sensor in darkness, 0.08 mA of current was drawn. Voc = 0.745 V therefore the internal source resistance = 9.3 k ohm (ignoring meter internal impedance). Similar source impedance is seen if testing from IRQ to Vcc.

The sensor is not able to sink very much current in darkness, and only pulls Voc down to 0.745V.

> Using a 1 k ohm resistor connected from IRQ to ground, with the sensor illuminated, 2.58 mA of current was drawn. Voc = 3.333 V therefore the internal source resistance = 292 ohm.

His test in bright light shows the sensor is able to output 2.58mA through a 1k resistor, thus if a pull-down was used in the order of 30k the sensor should easily be able to 'drive up' to 3.3V.

I believe the 0.1uF cap works for a few possible reasons:
. light leakage.
. lighting can flicker.
. EM noise, especially from mains cabling.
. Noise at the device from radio, RPi, emonTH etc..

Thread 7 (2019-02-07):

Terminals incorrectly labelled on v2 pcb

pb66, 2019-02-07:
See https://community.openenergymonitor.org/t/emonth-v2-0-2-terminal-block-assignment-question/10013?u=pb66

The 1wire temperature sensor data terminal is labelled "A5" when it is in fact the "A3" terminal that is used.

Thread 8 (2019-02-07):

Omissions in the v2 schematic

pb66, 2019-02-07:
See https://community.openenergymonitor.org/t/emonth-v2-0-2-terminal-block-assignment-question/10013?u=pb66

The "SDA" and "SCL" traces and labels are missing from the temperature/humidity sensor.

And the "ADC3" label is missing from the terminal blocks.

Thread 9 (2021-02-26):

Adding sd card

jsqu4re, 2021-02-26:
Hi! This looks like a really cool project! Do you feel it is simple to add an sd card to the emonth2 or are the required pins not available on the board?

glynhudson, 2021-02-28:
Thanks. It should be possible, however the SD card connects vis SPI as does the RFM69CW. It's possible to have multiple SPI devices on the same bus, you will just need to handle the slave select lines. Let us know how you get on. I would recommend posting on our community forum, someone may have done this before: https://community.openenergymonitor.org/

jsqu4re, 2021-03-01:
Thanks for the quick answer!!

Closed 2021-03-01.

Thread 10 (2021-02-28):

Arduino IDE - 'showString' was not declared in this scope

MikeBookham, 2021-02-28:
Using the Arduino IDE on Ubuntu 20.10 an error with '**showString’** was not declared in this scope was encountered within **master/firmware/src/src.ino**
The solution is to add:
`static void showString(PGM_P s);`

SlyRemarks, 2021-10-04:
Thank you, @MikeBookham. I'm so sorry your comment was overlooked for so long.

The line `static void showString(PGM_P s);` has been included in the latest release, V3.2.6.

Closed 2021-10-04.

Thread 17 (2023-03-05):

Firmware improvements

jonathandreyer, 2023-03-05:
Hello @TrystanLea, Hello everyone,

As explain in issue #15 related to the customization of encrypted key ([here](https://github.com/openenergymonitor/emonth2/issues/15#issuecomment-1447225896)), what do you think of improvement code by cleanup code (remove excess space, ..) & activate CI to builds the firmware automatically.
I have already created two branches ([clean-code](https://github.com/jonathandreyer/emonth2/tree/clean-code) & [ci](https://github.com/jonathandreyer/emonth2/tree/ci)) to track these improvements.

Best regards,

Jonathan Dreyer

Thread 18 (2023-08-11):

DIP adjusted nodeID not being used when using LPL radio format

greeebs, 2023-08-11:
https://github.com/openenergymonitor/emonth2/blob/e836d42bd4eac74fb98b36637aa6992f8c338fd5/firmware/emonth2.ino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

Should this line use "nodeID" instead of "EEPROM.nodeID"?

See: https://community.openenergymonitor.org/t/emonth-2-with-3-external-probes-nothing-received/24133/19

glynhudson, 2023-08-21:
Thanks, this has been fixed by https://github.com/openenergymonitor/emonth2/commit/8c13786c70e0dcced7f3c87a8846602e7b9ce7dc

Closed 2023-08-21.

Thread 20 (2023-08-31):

ISP header too close to battery holder

stuartpittaway, 2023-08-31:
The ISP header is difficult to use as the plug catches the side of the battery holder - consider moving 3 or 4mm away.

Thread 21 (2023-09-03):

Calibration mode entry timeout of 2 seconds is too short (v4.1.5)

nmcgann, 2023-09-03:
It is very tricky to type all the characters required to enter calibration mode within 2 seconds. I am using Putty on a PC so it means typing +, + , +, control-shift-m, control-shift-j (with the + characters requiring a shift too on my laptop keyboard).

[note: unmodified Putty does not have a way of sending \r\n in a single keystroke]

The original 5 seconds would be much easier, I can do it in 4 without having to do anything special like leaving a finger pressing the shift key down.

glynhudson, 2023-09-03:
I agree, I've increased the delay to 4s. This should be enough time

Closed 2023-09-03.

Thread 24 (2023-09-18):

Node address DIP switch pin pullups consuming excess power when switches are set "on"

nmcgann, 2023-09-18:
The two dip switch node address select pins (dip 1 and dip2) have internal pullups turned on with a value of 20k-50k. This amounts to between 66uA and 165uA continuous drain per pin with a 3.3V supply voltage when the switch is closed.

Solution is to turn off the pullup for switches set to zero so there is no static power drain.
`if (!dip1)
    pinMode(DIP_switch1, INPUT);
  if (!dip2)
    pinMode(DIP_switch2, INPUT);`

The obvious place to do it is in the power saving section of `emonth2.ino` when the other power saving measures are enacted.

Closed 2023-09-20.

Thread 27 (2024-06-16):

Firmware page missing images

reedy, 2024-06-16:
https://docs.openenergymonitor.org/emonth2/firmware.html

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

>emonPi to emonTh2 programmer image

and

>emonTh firmware upload image

seem to be missing images.

I'm guessing the first image is supposed to be the image referred to in the below:

>The example images below show the earlier Wicked Device / OpenEnergyMonitor Programmer

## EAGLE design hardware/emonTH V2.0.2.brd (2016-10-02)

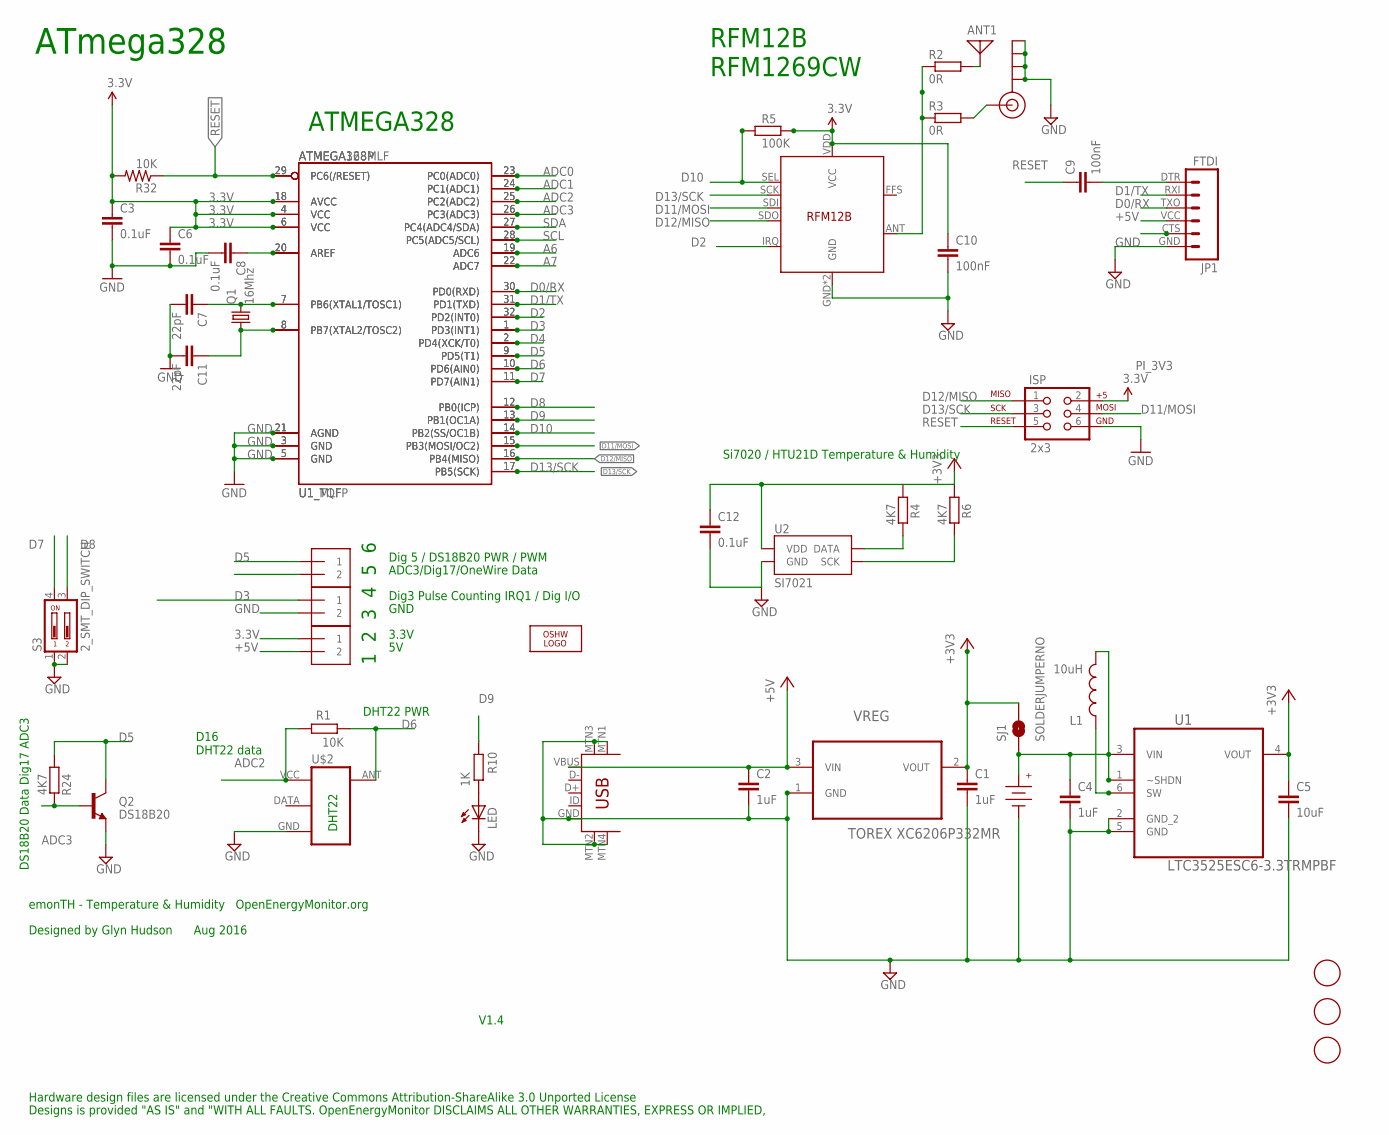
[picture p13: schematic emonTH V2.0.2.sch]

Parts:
ANT1: ANTENNA; PAD-01
C1, C2, C4: 1uF; C0603
C3, C6, C8, C12: 0.1uF; C0603
C5: 10uF; C0603
C7, C11: 22pF; C0603
C9, C10: 100nF; C0603
ISP: 2x3; 2X3
J1, J2, J3: 1X2-3.5MM
J$1: SMA_EDGE; SMA-EDGE
JP1: FTDI; FTDI_BASIC
L1: 10uH; 1210
LED: LEDCHIPLED-0603-TTW; CHIPLED-0603-TTW
LOGO2: OSHW_LOGO_10MILX0200-NT; OSHW_10X200_NOTEXT
Q1: 16Mhz; HC49UP
Q2: DS18B20; TO-92
R1, R32: 10K; R0603
R2, R3: 0R; R0603
R4, R6, R24: 4K7; R0603
R5: 100K; R0603
R10: 1K; R0603
RFM69CW: RFM12B
S3: 2_SMT_DIP_SWITCH; DIP_SWITCH_SMT
SJ1: SOLDERJUMPERNO; SJ_2S-NO
U1: LTC3525ESC6-3.3TRMPBF; SOT65P210X100-6N
U1_MLF: ATMEGA168MLF; MLF32
U1_TQFP: ATMEGA328P; TQFP32-08
U2: SI7021
U$1, U$6, U$7: FIDUCIAL; FIDUCIAL_1MM
U$2: RF-LINK_TX
U$3: 3V; AAA_PCB_HOLDER
U$5: USB-MINIB-5PIN; USB-MINIB-CISECO
VREG: TOREX XC6206P332MR; SOT95P237X112-3N

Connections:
3.3V: C1.1, C3.1, C5.1, C6.1, C10.1, C12.1, ISP.2, J3.1, R4.1, R5.2, R6.1, R32.2, RFM69CW.VDD (VCC), SJ1.2, U1.4 (VOUT), U1_MLF.4 (VCC), U1_MLF.6 (VCC), U1_MLF.18 (AVCC), U1_TQFP.4 (VCC), U1_TQFP.6 (VCC), U1_TQFP.18 (AVCC), U2.VDD, VREG.2 (VOUT)
+5V: C2.1, J3.2, JP1.VCC (4), U$5.VBUS, VREG.3 (VIN)
A6: U1_MLF.19 (ADC6), U1_TQFP.19 (ADC6)
A7: U1_MLF.22 (ADC7), U1_TQFP.22 (ADC7)
ADC0: U1_MLF.23 (PC0(ADC0)), U1_TQFP.23 (PC0(ADC0))
ADC1: C4.1, L1.2, SJ1.1, U1.1 (~SHDN), U1.3 (VIN), U1_MLF.24 (PC1(ADC1)), U1_TQFP.24 (PC1(ADC1)), U$3.+
ADC2: R1.2, U1_MLF.25 (PC2(ADC2)), U1_TQFP.25 (PC2(ADC2)), U$2.VCC (+5V)
ADC3: J1.2, Q2.2 (B), R24.2, U1_MLF.26 (PC3(ADC3)), U1_TQFP.26 (PC3(ADC3))
D0/RX: JP1.TXO (3), U1_MLF.30 (PD0(RXD)), U1_TQFP.30 (PD0(RXD))
D1/TX: JP1.RXI (2), U1_MLF.31 (PD1(TXD)), U1_TQFP.31 (PD1(TXD))
D2: RFM69CW.IRQ, U1_MLF.32 (PD2(INT0)), U1_TQFP.32 (PD2(INT0))
D3: J2.1, U1_MLF.1 (PD3(INT1)), U1_TQFP.1 (PD3(INT1))
D4: U1_MLF.2 (PD4(XCK/T0)), U1_TQFP.2 (PD4(XCK/T0))
D5: J1.1, Q2.3 (C), R24.1, U1_MLF.9 (PD5(T1)), U1_TQFP.9 (PD5(T1))
D6: R1.1, U1_MLF.10 (PD6(AIN0)), U1_TQFP.10 (PD6(AIN0)), U$2.ANT
D7: S3.4, U1_MLF.11 (PD7(AIN1)), U1_TQFP.11 (PD7(AIN1))
D8: S3.3, U1_MLF.12 (PB0(ICP)), U1_TQFP.12 (PB0(ICP))
D9: R10.2, U1_MLF.13 (PB1(OC1A)), U1_TQFP.13 (PB1(OC1A))
D10: R5.1, RFM69CW.SEL, U1_MLF.14 (PB2(SS/OC1B)), U1_TQFP.14 (PB2(SS/OC1B))
D11/MOSI: ISP.4, RFM69CW.SDI, U1_MLF.15 (PB3(MOSI/OC2)), U1_TQFP.15 (PB3(MOSI/OC2))
D12/MISO: ISP.1, RFM69CW.SDO, U1_MLF.16 (PB4(MISO)), U1_TQFP.16 (PB4(MISO))
D13/SCK: ISP.3, RFM69CW.SCK, U1_MLF.17 (PB5(SCK)), U1_TQFP.17 (PB5(SCK))
DIG1: R2.1, R3.1, RFM69CW.ANT
GND: C1.2, C2.2, C3.2, C4.2, C5.2, C6.2, C7.2, C8.2, C10.2, C11.2, C12.2, ISP.6, J2.2, J$1.GND@0 (GND), J$1.GND@1 (GND), J$1.GND@2 (GND), J$1.GND@3 (GND), JP1.GND (6), LED.C, Q2.1 (E), RFM69CW.GND, RFM69CW.P$12 (GND), S3.1, S3.2, U1.2 (GND_2), U1.5 (GND), U1_MLF.3 (GND), U1_MLF.5 (GND), U1_MLF.21 (AGND), U1_TQFP.3 (GND), U1_TQFP.5 (GND), U1_TQFP.21 (AGND), U2.GND, U$2.GND, U$3.-, U$5.GND, U$5.MTN1 (MTN2), U$5.MTN2 (MTN3), U$5.MTN3 (MTN1), U$5.MTN4, VREG.1 (GND)
unnamed: LED.A, R10.1
unnamed: C7.1, Q1.2, U1_MLF.7 (PB6(XTAL1/TOSC1)), U1_TQFP.7 (PB6(XTAL1/TOSC1))
unnamed: L1.1, U1.6 (SW)
unnamed: C11.1, Q1.1, U1_MLF.8 (PB7(XTAL2/TOSC2)), U1_TQFP.8 (PB7(XTAL2/TOSC2))
unnamed: ANT1.1, R2.2
unnamed: C8.1, U1_MLF.20 (AREF), U1_TQFP.20 (AREF)
unnamed: C9.2, JP1.DTR (1)
unnamed: J$1.SIG (SIGNAL), R3.2
RESET: C9.1, ISP.5, R32.1, U1_MLF.29 (PC6(/RESET)), U1_TQFP.29 (PC6(/RESET))
SCL: R6.2, U1_MLF.28 (PC5(ADC5/SCL)), U1_TQFP.28 (PC5(ADC5/SCL)), U2.SCK
SDA: R4.2, U1_MLF.27 (PC4(ADC4/SDA)), U1_TQFP.27 (PC4(ADC4/SDA)), U2.DATA

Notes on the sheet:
emonTH - Temperature & Humidity OpenEnergyMonitor.org
Designed by Glyn Hudson Aug 2016
V1.4
DS18B20 Data Dig17 ADC3
ADC3/Dig17/OneWire Data
Dig 5 / DS18B20 PWR / PWM
Dig3 Pulse Counting IRQ1 / Dig I/O
GND
3.3V
DHT22
1 2 3 4 5 6
Hardware design files are licensed under the Creative Commons Attribution-ShareAlike 3.0 Unported License
Designs is provided "AS IS" and "WITH ALL FAULTS. OpenEnergyMonitor DISCLAIMS ALL OTHER WARRANTIES, EXPRESS OR IMPLIED,
ATmega328
ATMEGA328
RFM12B RFM1269CW
D16 DHT22 data
Si7020 / HTU21D Temperature & Humidity
DHT22 PWR

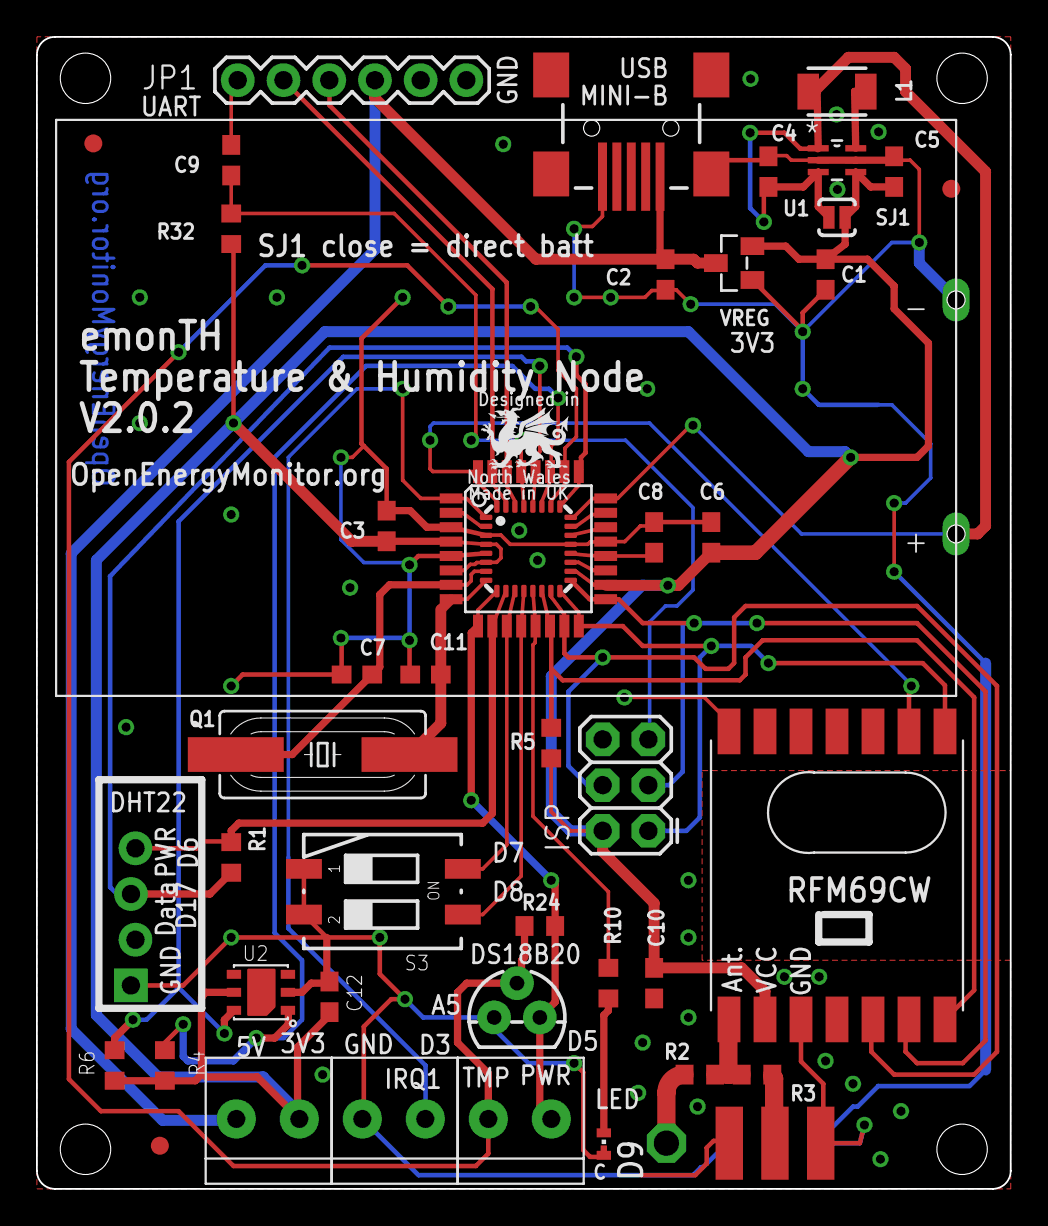
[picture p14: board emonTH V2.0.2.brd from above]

Board: 2 copper layers, 54.1 x 64.0 mm, 47 parts (1 on the bottom side), 35 nets.

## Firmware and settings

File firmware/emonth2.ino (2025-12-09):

/*
  emonTH V2 Low Power SI7021 Humidity & Temperature, DS18B20 Temperature & Pulse counting Node Example

  Si7021 = internal temperature & Humidity
  DS18B20 = External temperature


  Part of the openenergymonitor.org project
  Licence: GNU GPL V3

  Authors: Glyn Hudson
  Builds upon JCW JeeLabs RF12 library, Arduino and Martin Harizanov's work

  THIS SKETCH REQUIRES:

  Libraries required:
   - see platform io.ini
   - recommend compiling with platformIO for auto library download https://guide.openenergymonitor.org/technical/compiling
   - Arduino IDE can be used to compile but libs will need to be manually downloaded

  Recommended node ID allocation
  -----------------------------------------------------------------------------------------------------------
  -ID-	-Node Type-
  0	- Special allocation in JeeLib RFM12 driver - reserved for OOK use
  1-4     - Control nodes
  5-10	- Energy monitoring nodes
  11-14	--Un-assigned --
  15-16	- Base Station & logging nodes
  17-30	- Environmental sensing nodes (temperature humidity etc.)
  31	- Special allocation in JeeLib RFM12 driver - Node31 can communicate with nodes on any network group
  -------------------------------------------------------------------------------------------------------------
  */

const char *firmware_version = {"4.2.1"};
/*

  Change log:
  v4.2.1   - (09/12/25) Fix option to change frequency via serial config
  v4.2.0   - (09/12/25) Change transmit frequency to 433.92 MHz
  V4.1.8   - (28/03/25) Use of minimal RFM69_LPL library to add while loop timeouts (issue unclear)
  V4.1.7   - (05/03/24) Fix node ID DIP switch selection (again)
  V4.1.6   - (26/02/24) Fix DS18B20 serial printing & multiple sensors 
  V4.1.5   - (21/08/23) Fix node ID DIP switch selection 
  V4.1.4   - (21/07/23) Serial print RF format  
  V4.1.3   - (05/06/23) Startup serial print streamline for factory test 
  V4.1.2   - (27/02/23) Add option to used custom encryption key
  V4.1.1   - (19/02/23) Fix missing frequency initialization
  V4.1.0   - (17/02/23) LowPowerLabs radio format option
  V4.0.0   - (10/07/21) Replace JeeLib with OEM RFM69nTxLib using RFM69 "Native" packet format, add emonEProm library support
  
  V3.2.4   - (25/05/18) Add prompt for serial config
  V3.2.3   - (17/07/17) Fix DIP switch had no effect
  V3.2.2   - (12/05/17) Fix DIP switch nodeID not being read when EEPROM is configures
  V3.2.1   - (30/11/16) Fix emonTx port typo
  V3.2.0   - (13/11/16) Run-time serial nodeID config
  V3.1.0   - (19/10/16) Test for RFM69CW and SI7021 at startup, allow serial use without RF precent
  V3.0.0   - (xx/10/16) Add support for SI7021 sensor instead of DHT22 (emonTH V2.0 hardware)
  ^^^ emonTH V2.0 hardware ^^^
  V2.7   - (15/09/16) Serial print serial pairs for EmonEsp compatible e.g. temp:210,humidity:56
  V2.6   - (24/10/15) Tweek RF transmission timing to help reduce RF packet loss
  V2.5   - (23/10/15) default nodeID 23 to enable new emonHub.conf decoder for pulseCount packet structure
  V2.4   - (15/10/15) activate pulse count pin input pullup to stop spurious pulses when no sensor connected
  v2.3.1 - (12/10/14) don't flash LED on RF transmission to save power
  v2.3   - rebuilt based on low power pulse counting code by Eric Amann: http://openenergymonitor.org/emon/node/10834
  v2.2   - 60s RF transmit period now uses timer1, pulse events are decoupled from RF transmit
  v2.4   - 5 min default transmission time = 300 ms
  v2.1   - Branched from emonTH_DHT22_DS18B20 example, first version of pulse counting version
 -------------------------------------------------------------------------------------------------------------
  emonhub.conf node decoder:
  See: https://github.com/openenergymonitor/emonhub/blob/emon-pi/configuration.md

   For 1x external sensor (default):
    [[23]]
      nodename = emonth2_23
      [[[rx]]]
         names = temperature, external temperature, humidity, battery, pulsecount
         datacodes = h,h,h,h,L
         scales = 0.1,0.1,0.1,0.1,1
         units = C,C,%,V,p
   
   For 4x external sensors  (#define EXTERNAL_TEMP_SENSORS 4):
   
    [[23]]
        nodename = emonth2_23
        [[[rx]]]
            names = temperature, external temperature1, external temperature2, external temperature3, external temperature4, humidity, battery, pulsecount
            datacodes = h, h, h, h, h, h, h, L
            scales = 0.1, 0.1, 0.1, 0.1, 0.1, 0.1, 0.1, 1.0
            units = C, C, C, C, C, %, V, p    
         
         
         
  */
// -------------------------------------------------------------------------------------------------------------

// #define ATTINY                                                      // Uncomment for attiny

#define RFM69_JEELIB_CLASSIC 1
#define RFM69_JEELIB_NATIVE 2
#define RFM69_LOW_POWER_LABS 3

// Set in platformio.ini
//#define RadioFormat RFM69_LOW_POWER_LABS

bool flash_led = false;                                                // true = Flash LED after each sample (increases battery drain)

// These variables control the transmit timing of the emonTH
const unsigned long WDT_PERIOD = 80;                                   // mseconds.
const unsigned long WDT_MAX_NUMBER = 690;                              // Data sent after WDT_MAX_NUMBER periods of WDT_PERIOD ms without pulses:
                                                                       // 690 × 80 = 55.2 seconds (it needs to be about 5s less than the record interval in emoncms)
const unsigned long PULSE_MAX_NUMBER = 100;                            // Data sent after PULSE_MAX_NUMBER pulses
#define RFM69CW                                                        // Use the RFM69CW radio

#if RadioFormat == RFM69_LOW_POWER_LABS
  #include <RFM69_LPL.h>                             // RFM69 LowPowerLabs radio library
#elif RadioFormat == RFM69_JEELIB_CLASSIC
  #include <rfmTxLib.h>                          // RFM69 transmit-only library using "JeeLib RFM69 Native" message format
#elif RadioFormat == RFM69_JEELIB_NATIVE
  #include <rfm69nTxLib.h>                       // RFM69 transmit-only library using "JeeLib RFM69 Native" message format
#endif

#include <emonEProm.h>                                                 // OEM EEPROM library
#ifndef ATTINY
  #include <JeeLib.h>
#endif
#include <avr/power.h>
#include <avr/sleep.h>
#include <OneWire.h>
#include <DallasTemperature.h>
// Include EmonTH_V2_config.ino in the same directory as this for configuration functions & data


#define REG_SYNCVALUE1 0x2F
#define MAX_SENSORS 4                                                  // The maximum number of external temperature sensors.
                                                                                                                                      
#define EXTERNAL_TEMP_SENSORS 1                                        // Specify number of external temperature sensors connected                                                                      
                                                                       
#define FACTORYTESTGROUP 1                                             // Transmit the Factory Test on Grp 1 
                                                                       //   to avoid interference with recorded data at power-up.

//---------------------------- emonTH Settings - Stored in EEPROM and shared with config.ino ------------------------------------------------
struct 
{
  byte RF_freq = RF69_433_92MHZ;                                       // Frequency of radio module can be RF69_433MHZ, RF69_868MHZ or RF69_915MHZ. 
  byte networkGroup = 210;                                             // Wireless network group, must be the same as emonBase / emonPi and emonGLCD. OEM default is 210
  byte  nodeID = 23;                                                   // Node ID for this sensor.
  byte  rf_on = 1;                                                     // RF/Serial output. Bit 0 set: RF on, bit 1 set: serial on.
  byte  rfPower = 25;                                                  // 0 - 31 = -18 dBm (min value) - +13 dBm (max value). RFM12B equivalent: 25 (+7 dBm)
                                                                       //    lower power means increased battery life
  bool  pulse_enable = false;                                          // Pulse counting
  int   pulse_period = 50;                                             // Pulse min period - 0 = no de-bounce
  bool  temperatureEnabled = false;                                    // Enable external temperature measurement
  DeviceAddress allAddresses[MAX_SENSORS];                             // External sensor address data
} EEProm;

uint16_t eepromSig = 0xFF06;                                           // 'Experimental' signature - see oemEProm Library documentation for details.
bool calibration_enable = false;                                       // Start with calibration disabled
byte nodeID = EEProm.nodeID;
byte last_nodeID = 0;                                                  // Last node ID used for RFM69CW
const int busyThreshold = -97;                                         // Signal level below which the radio channel is clear to transmit
const byte busyTimeout = 0;                                            // Time in ms to wait for the channel to become clear, before transmitting anyway. Set to zero to
                                                                       //   inhibit channel occupancy check (conserves battery life but increases the risk of lost messages)
                                                                       //   Recommended value when used: 15 (ms)


#if RadioFormat == RFM69_LOW_POWER_LABS
  RFM69 radio;
#endif

const int TEMPERATURE_PRECISION = 11;                                  // DS18B20 resolution 9,10,11 or 12bit corresponding to (0.5, 0.25, 0.125, 0.0625 degrees C LSB),
                                                                       // lower resolution means lower power
                                                                       // 9 (93.8ms), 10 (187.5ms), 11 (375ms) or 12 (750ms) bits equal to resolution of 0.5C, 0.25C, 0.125C and 0.0625C
#define ASYNC_DELAY 375                                                // 9bit requires 95ms, 10bit 187ms, 11bit 375ms and 12bit resolution takes 750ms
// See block comment above for library info
ISR(WDT_vect) { 
  #ifndef ATTINY
  Sleepy::watchdogEvent(); 
  #endif
}                             // Attach JeeLib sleep function to Atmega328 watchdog - enables MCU to be put into sleep mode inbetween readings to reduce power consumption

// SI7021_status SPI temperature & humidity sensor
#include <Wire.h>
#include <SI7021.h>
SI7021 SI7021_sensor;
bool SI7021_status;

// Hardwired emonTH pin allocations
const byte DS18B20_PWR =    5;
const byte LED =            9;
const byte BATT_ADC =       1;
const byte DIP_switch1 =    7;
const byte DIP_switch2 =    8;
const byte pulse_count_pin =3;                                         // INT 1 / Dig 3 Screw Terminal Block Number 4
#define ONE_WIRE_BUS       17
const byte DHT22_PWR =      6;                                         // Not used in emonTH V2.0, 10K resistor R1 connects DHT22 pins
const byte DHT22_DATA =    16;                                         // Not used in emonTH V2.0, 10K resistor R1 connects DHT22 pins.

bool dip1;                                                             // DIP switch state
bool dip2;                                                             // DIP switch state

OneWire oneWire(ONE_WIRE_BUS);
DallasTemperature sensors(&oneWire);

// Note: Please update emonhub configuration guide on OEM wide packet structure change:
// https://github.com/openenergymonitor/emonhub/blob/emon-pi/configuration.md
typedef struct 
{                                                                      // RFM RF payload datastructure
  int temp;
  int temp_external[EXTERNAL_TEMP_SENSORS];
  int humidity;
  int battery;
  unsigned long pulsecount;
} Payload;
Payload emonth;

int numSensors;                                                        // The number of external DS18B20 sensors found

volatile unsigned long pulseCount;
unsigned long WDT_number;
bool newPulse;

unsigned long now, start;
const byte SLAVE_ADDRESS = 42;


static void showString (PGM_P s);

//################################################################################################################################
//################################################################################################################################
#ifndef UNIT_TEST // IMPORTANT LINE! // http://docs.platformio.org/en/stable/plus/unit-testing.html

void setup() 
{
//################################################################################################################################

  pinMode(LED,OUTPUT); digitalWrite(LED,HIGH);                         // Status LED on

  // Unused pins configure as input pull up for low power
  // http://electronics.stackexchange.com/questions/43460/how-should-unused-i-o-pins-be-configured-on-atmega328p-for-lowest-power-consumpt
  // port map: https://github.com/openenergymonitor/emonth2/blob/master/hardware/readme.md
  pinMode(DHT22_PWR, INPUT_PULLUP);                                    // DHT22 not used on emonTH V2.
  pinMode(DHT22_DATA, INPUT_PULLUP);                                   // DHT22 not used on emonTH V2
  pinMode(14, INPUT_PULLUP);
  pinMode(20, INPUT_PULLUP);
  pinMode(21, INPUT_PULLUP);
  pinMode(4, INPUT_PULLUP);

  //READ DIP SWITCH POSITIONS - LOW when switched on (default off - pulled up high)
  pinMode(DIP_switch1, INPUT_PULLUP);
  pinMode(DIP_switch2, INPUT_PULLUP);
  dip1 = digitalRead(DIP_switch1);
  dip2 = digitalRead(DIP_switch2);

  Serial.begin(115200);
  Serial.println("OpenEnergyMonitor.org");
  Serial.print("emonTH FW: V"); Serial.println(firmware_version);
  delay(100);

  load_config(true);                                                   // Load RF config from EEPROM (if any exists)
  
  if (EEProm.rf_on)
  {
    list_calibration();
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
void loop()
//################################################################################################################################
{
  if (newPulse) {
    #ifndef ATTINY
    Sleepy::loseSomeTime(EEProm.pulse_period);
    #endif
    newPulse = false;
  }

  #ifndef ATTINY
  if (Sleepy::loseSomeTime(WDT_PERIOD)==1) {
    WDT_number++;
  }
  #endif

  if (WDT_number>=WDT_MAX_NUMBER || pulseCount>=PULSE_MAX_NUMBER)
  {
    if (EEProm.pulse_enable)
    {
      cli();
      emonth.pulsecount += pulseCount;
      pulseCount = 0;
      sei();
    }


    if (numSensors && EEProm.temperatureEnabled)
    {
      digitalWrite(DS18B20_PWR, HIGH); dodelay(50);
      for(int j=0;j<numSensors;j++) {
        sensors.setResolution(EEProm.allAddresses[j], TEMPERATURE_PRECISION);      // and set the a to d conversion resolution of each.
      }
      sensors.requestTemperatures();                                   // Send the command to get temperatures
      dodelay(ASYNC_DELAY);                                            //Must wait for conversion, since we use ASYNC mode
      
      for(int j=0;j<EXTERNAL_TEMP_SENSORS;j++) {
        float temp=(sensors.getTempC(EEProm.allAddresses[j]));
        if ((temp < 125.0) && (temp > -40.0)) {
          emonth.temp_external[j] = (temp*10);
        }
      }
      digitalWrite(DS18B20_PWR, LOW);
    }

    emonth.battery=int(analogRead(BATT_ADC)*0.0322);                   //read battery voltage, convert ADC to volts x10

    //Enhanced battery monitoring mode. In this mode battery values
    //sent in x*1000 mode instead of x*10. This allows to have more accurate
    //values on emonCMS x.xx instead of x.x
    // NOTE if you are going to enable this mode you need to
    // 1. Disable x*10 mode. By commenting line above.
    // 2. Change multiplier in line 353 Serial.print(emonth.battery/10.0);
    // 3. Change scales factor in the emonhub node decoder entry for the emonTH
    // See more https://community.openenergymonitor.org/t/emonth-battery-measurement-accuracy/1317
    //emonth.battery=int(analogRead(BATT_ADC)*3.222);

    // Read SI7021
    // Read from SI7021 SPI temp & humidity sensor
    if (SI7021_status==1)
    {
      #ifndef ATTINY
      power_twi_enable();
      #endif
      si7021_env data = SI7021_sensor.getHumidityAndTemperature();
      emonth.temp = (data.celsiusHundredths*0.1);
      emonth.humidity = (data.humidityBasisPoints*0.1);
      #ifndef ATTINY
      power_twi_disable();
      #endif
    }


    // Send data via RF
    if (EEProm.rf_on & 0x01)
    {
      #ifndef ATTINY
      power_spi_enable();
      #endif
      dodelay(30);                                                     // wait for module to wakup
      #if RadioFormat == RFM69_LOW_POWER_LABS
        if (last_nodeID != nodeID) {
          radio.setAddress(nodeID);
          last_nodeID = nodeID;
        }
        radio.send_csma(5, (const void*)(&emonth), sizeof(emonth), busyTimeout);
        radio.sleep();
      #else
        rfm_send((byte *)&emonth, sizeof(emonth), EEProm.networkGroup, nodeID, EEProm.RF_freq, EEProm.rfPower, busyThreshold, busyTimeout);
      #endif
      dodelay(100);
      #ifndef ATTINY
      power_spi_disable();
      #endif
    }

    if (flash_led)
    {
      digitalWrite(LED,HIGH);
      dodelay(100);
      digitalWrite(LED,LOW);
    }

    if (EEProm.rf_on & 0x02)
    {
      // Serial print strings pairs e.g. "temp:2634,humidity:4010,batt:33"
      // Works with EmonESP direct serial
      Serial.print("temp:");Serial.print(emonth.temp); Serial.print(",");

      if (numSensors)
      {
        for(int j=0;j<EXTERNAL_TEMP_SENSORS;j++) {
          Serial.print("tempex");Serial.print(j);Serial.print(":");Serial.print(emonth.temp_external[j]); Serial.print(",");
        }
      }

      if (SI7021_status)
      {
        Serial.print("humidity:");Serial.print(emonth.humidity); Serial.print(",");
      }
      Serial.print("batt:"); Serial.print(emonth.battery);
      if (emonth.pulsecount > 0) 
      {
        Serial.print(",");
        Serial.print("pulse:"); Serial.print(emonth.pulsecount);
      }
      Serial.println();
      delay(5);
    } // end serial print


    now = millis();
    WDT_number=0;
  } // end WDT

} // end loop

void dodelay(unsigned int ms)
{
  #ifndef ATTINY
  byte oldADCSRA=ADCSRA;
  byte oldADCSRB=ADCSRB;
  byte oldADMUX=ADMUX;

  Sleepy::loseSomeTime(ms); // JeeLabs power save function: enter low power mode for x seconds (valid range 16-65000 ms)

  ADCSRA=oldADCSRA;         // restore ADC state
  ADCSRB=oldADCSRB;
  ADMUX=oldADMUX;
  #endif
}

  //################################################################################################################################
  // Interrupt pulse counting setup
  //################################################################################################################################
void startPulseCount(void)
{
  emonth.pulsecount = 0;
  pulseCount = 0;
  WDT_number=720;
  newPulse = false;
  attachInterrupt(digitalPinToInterrupt(pulse_count_pin), onPulse, RISING);
}

void stopPulseCount(void)
{
  detachInterrupt(digitalPinToInterrupt(pulse_count_pin));
}

// The interrupt routine - runs each time a rising edge of a pulse is detected
void onPulse()
{
  newPulse = true;                           // flag for new pulse set to true
  pulseCount++;                              // number of pulses since the last RF sent
}

void printTemperatureSensorAddresses(void)
{
  DeviceAddress *temperatureSensors = EEProm.allAddresses;
  Serial.print(F("DS18B20 found = "));
  Serial.print(numSensors);
  Serial.print(" of ");
  Serial.println(MAX_SENSORS);
  
  if (numSensors)
  {
      Serial.println(F(", with addresses..."));
      for (int j=0; j< numSensors; j++)
      {
          for (int i=0; i<8; i++)
          {
              if (temperatureSensors[j][i] < 0x10)
                Serial.print(F("0"));
              Serial.print(temperatureSensors[j][i], 16);
              Serial.print(F(" "));
          }
          if (temperatureSensors[j][6] == 0x03)
            Serial.print(F("Sensor may not be reliable"));
          Serial.println();
          delay(5);
      }
  }
  // Serial.println();
  // Serial.print(F("DS18B20 measurement is"));
  // Serial.print(EEProm.temperatureEnabled?"":" NOT");
  // Serial.println(F(" enabled."));
  delay(5);
        
}


#endif    // IMPORTANT LINE! end unit test
//http://docs.platformio.org/en/stable/plus/unit-testing.html

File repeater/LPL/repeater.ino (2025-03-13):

#include <RFM69.h>
RFM69 radio;

byte nativeMsg[66];

#define MAXMSG 66
char outmsg[MAXMSG];
byte outmsgLength;

struct {
  byte srcNode = 0;
  byte msgLength = 0;
  signed char rssi = -127;
  bool crc = false;
} rfInfo;

void setup() 
{
  Serial.begin(38400);
  //Serial.println("Repeater");
  radio.initialize(RF69_433MHZ,5,200);  
  radio.encrypt("89txbe4p8aik5kt3");
  radio.setPowerLevel(31);
}

void loop()             
{
  if (radio.receiveDone())
  {
    rfInfo.srcNode = radio.SENDERID;
    rfInfo.msgLength = radio.DATALEN;
    for (byte i = 0; i < radio.DATALEN; i++) {
      nativeMsg[i] = radio.DATA[i];
    }
    rfInfo.rssi = radio.readRSSI();
    
    if (radio.ACKRequested()) {
      radio.sendACK();
    }
    
    Serial.print(F("OK")); 
    Serial.print(F(" "));
    Serial.print(rfInfo.srcNode, DEC);
    Serial.print(F(" "));
    for (byte i = 0; i < rfInfo.msgLength; i++) {
      Serial.print((word)nativeMsg[i]);
      Serial.print(F(" "));
    }
    Serial.print(F("("));
    Serial.print(rfInfo.rssi);
    Serial.print(F(")"));
    Serial.println();
    
    // Repeat
    radio.setAddress(rfInfo.srcNode);
    radio.setNetwork(210);
    radio.sendWithRetry(5, nativeMsg, rfInfo.msgLength);
    radio.setAddress(5);
    radio.setNetwork(200);
  }
}

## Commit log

2016-09-20 add sensor test & readme
2016-09-24 add hardware
    [emonTH V2.0.1.brd, emonTH V2.0.1.sch]
2016-09-24 add hardware readme
    [emonTH V2.0.1.brd]
2016-09-24 crop brd fix bom
2016-09-26 add emonth v2.0.2
    [emonTH V2.0.2.brd, emonTH V2.0.2.sch]
2016-09-26 add v2.0.2 gerbers
    [emonTH V2.0.1.brd, emonTH V2.0.1.sch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]
2016-09-26 correct DH18B20 pin number
2016-09-28 power tweak & add power trace
2016-09-29 unused inputs configure as input pull-up for low power
2016-09-30 update portmap & sch + brd img
    [emonTH V2.0.2.sch]
2016-09-30 minor typos
    [emonTH V2.0.2.brd]
2016-10-01 add battery life calcs
2016-10-04 re-do emonthv2 battery life estimate, batteris are in series :-)
2016-10-04 Revert "re-do emonthv2 battery life estimate, batteris are in series :-)"
    This reverts commit 3dbadf6331d72acecde24984a721b79868487637.
2016-10-04 battery capacity is 2xAA because of boost converter
2016-11-29 add board photo
2017-01-17 add emonth2 octopart bom
    [20170117_emonth_v2_0_2.csv]
2017-05-12 V3.2.2 fix DIP switches not being read when EEPROM is configured
2017-07-26 Fix DIP switch had no effect (#2)
    * Fix DIP switch had no effect
    * don't devide version number in config function
2020-04-23 fix potential issue with case statement
2021-02-05 support for multiple external temperature sensors
2023-02-17 single external temperature sensor by default
2023-02-20 Fix missing frequency initialization
    [emonth2.ino]
2023-06-05 Serial print tweaks to enable factory test
2023-06-08 V4.1.3 serial print factory test optimisations
2023-07-21 serial print RF format
2023-08-21 Update emonth2.ino
    fix set address on LPL
    [emonth2.ino]
2023-09-03 increase config delay to 4s fix #21
    [emonth2_config.ino]
2023-09-04 serial config timeout fixes and improved error checking
    [emonth2_config.ino]
2023-09-20 Prevent dip switch pullups drawing power if switches closed (#25)
    [emonth2.ino]
2024-02-26 V4.1.6 Fix DS18B20 serial printing & multiple sensors
    [emonth2.ino, emonth2_config.ino]
2024-02-26 lower case
2024-03-05 V4.1.7 fix DIP swich nodeID config
    [emonth2.ino]
2025-11-27 Add documentation about using multiple external temperature probes (#29)

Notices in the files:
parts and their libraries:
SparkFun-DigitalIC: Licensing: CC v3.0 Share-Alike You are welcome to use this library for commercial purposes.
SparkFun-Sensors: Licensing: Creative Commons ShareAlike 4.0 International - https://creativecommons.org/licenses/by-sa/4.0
